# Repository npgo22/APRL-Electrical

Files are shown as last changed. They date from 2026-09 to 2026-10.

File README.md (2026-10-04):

# APRL KiCad Projects

APRL KiCad Projects.

## Setup
First, clone the repository with `git clone`. GitHub has a button which gives you the command to do this.
Then, you will have to use `git lfs pull` to get all the 3D models and images.

The projects here rely on `APRL_LIBS` and `KICAD_USER_TEMPLATE_DIR` being set. You can do this by:

1. Going to Preferences > Configure Paths...
2. Setting `APRL_LIBS` to wherever you cloned this repo + `/kicadlibs`.
3. Setting `KICAD_USER_TEMPLATE_DIR` to whatever you set in (2) + `/templates`

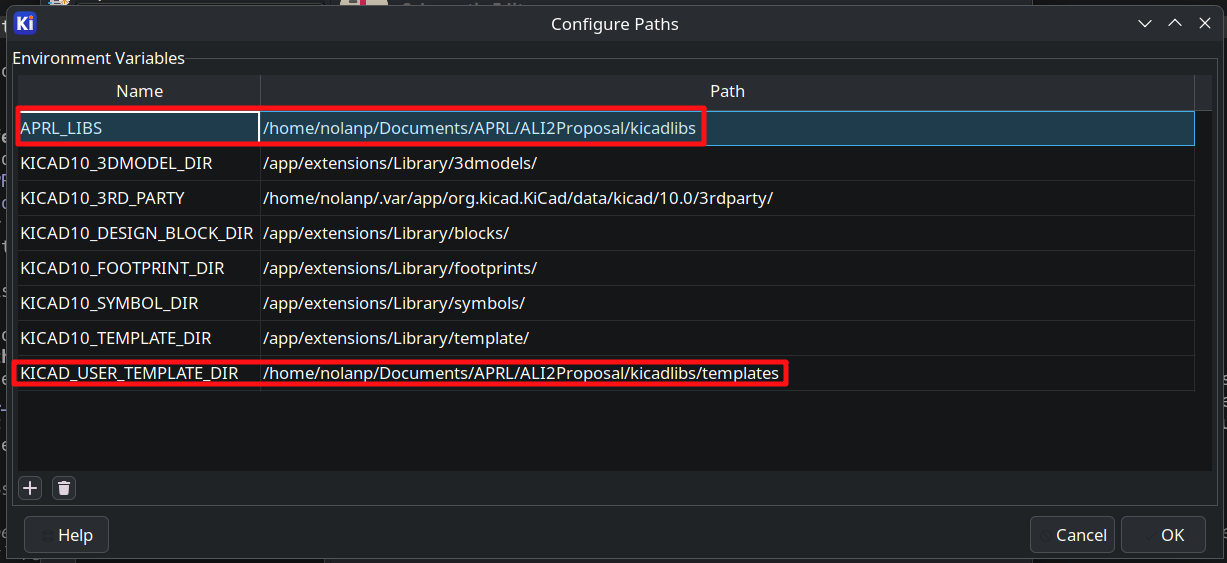
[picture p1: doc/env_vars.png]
Screenshot of the environment variables being set


## New ALI (Current Project for FQ2026)

### Design
The exigence of this endeavour is twofold:
1. To test the analog frontend designs of our proposed boards for DPF
2. To replace the confusing and elaborate ALI electronics with something that is far better documented and easier to use

The ALI itself can continue to be used for years to come and this reworking of the electronics will not impact it at all. This is going to be its own separate electrical box altogether. The ALI has the following additional limitations, too:
1. Limited I/O
2. Bonded grounds between +24/12/5V power supplies
3. Unknown board-level design decisions/trade-offs made in off-the-shelf components leading to strange artifacts in various measurements
4. Is generally really difficult to understand
5. Mixes bodge-wired custom electronics, off-the-shelf parts, and protoboards
6. Generally has fairly poor mounting
7. Makes use of fairly terrible connectors which are partially damaged and/or have shields which are not properly tied to case GND
8. Is completely full, thus making it impossible to add more electronics
9. Has no methods of cooling, sans the empty hold in the side of the box which completely negate the weather rating of the box itself
10. Uses heterogenous embedded computing ecosystems, requiring cross-domain knowledge of embassy, STM32Cube, and Arduino while doing every single one of them somewhat wrong in one way or another
11. Lacks feedback in many places (error logging namely)
12. Is generally just really hard to work with

Therefore, we have started work on a true replacement. Each of the modules serve a specific task, and are hooked to a common ethernet-based network which is far more performant than the original layout while simultaneously being easier to understand and expand. If you want more I/O, you can just simply add another board within a few minutes. Likewise, by opting for cutouts in the enclosure over dedicated port holes, it is also far easier to revise significant parts of the design without needing to drill through steel. 

#### Power
This system is +5V and +24V only, with +3.3V regulated on each board.

### CANBUS vs Ethernet
On the ground station, we are planning to use Ethernet instead of CANBUS. While this means our session protocol will not be tested in a real-world hotfire scenario, it does mean we can fully exploit each of the features offered by ethernet:
- Higher bandwidth (upwards of ~50x) means we don't have to throttle anything including error logging
- Natural isolation means we don't need any special tricks to get grounded thermocouples to work
- Is just generally far more pleasant to work with
- Does not limit future design decisions should we decide to reuse anything

Each of the modules will have a CAN transceiver anyway available for testing.

## Repository layout

```
kicadlibs/                                 Shared KiCad libraries, referenced as ${APRL_LIBS}
  aprl/                                      APRL's custom symbols and footprints
  aprl/*-noct.pretty                         "aprl/" but without courtyards
  vendor/                                    Third-party libs
  kicad/                                     Vendored stock KiCad libraries
  models/                                    3D models
  APRL_*_Sheet.kicad_wks                     Drawing sheets
  jlcpcb-4layer.kicad_dru                    Canonical JLCPCB design rules
.github/scripts                              Helper scripts runnable via Just and GH actions

ali/v2/                                    New ALI electronics
ali/v1/                                    Old ALI electronics
ophio/                                     DPF Vehicle Boards
misc/                                      Other endeavours
```

## What's not in this repo
- Old code (incl thermocouple 1A's CubeMX and Embassy variants)
- Prototypes (pending ordering)
- ALI ADC hardware (pending import)

## AI Usage
You may use AI to research topics and to write one-off scripts which do minor modifications and automate tedious, minor tasks. For example, if you need to color in a bunch of models feel free to.

What you *cannot* use it for is end to end electrical design, layout, and documentation. Documents should be written by people, and a schematic falls under this category. Likewise, using AI to automate layout is A. ineffective because it does not generate high-quality layouts and B. defeats the purpose of this club, which is to learn about electronics.

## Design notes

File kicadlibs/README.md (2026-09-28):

# KiCad Libraries

Libraries for KiCad. Reference them with `${APRL_LIBS}/...`, set to this folder
in Preferences -> Configure Paths.

## aprl/

First-party libs drawn by APRL. Every library is named `APRL_*`.

## kicad/

The stock KiCad libraries, vendored whole because KiCad devs hate electrical
engineers. Refresh with `just vendor-kicad-flatpak`.

## vendor/

Third-party libs generated by others.

## models/

3D models for every library, flat and keyed by filename. Referenced as
`${APRL_LIBS}/models/<file>`.

## Drawing sheets and rules

`APRL_Schematic_Sheet.kicad_wks`, `APRL_Layout_Sheet.kicad_wks` and
`jlcpcb-4layer.kicad_dru`. Title-block fields are project text variables.

## Adding a part

Symbol goes in the `APRL_*.kicad_sym` matching its function, footprint in the
matching `APRL_*.pretty`, 3D model in `models/`. Third-party parts go in
`vendor/`.

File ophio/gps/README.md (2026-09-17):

# Flight Computer / GPS (v1)

Flight computer board with GPS integration.

## KiBot

```sh
kibot -c gps.kibot.yaml
```

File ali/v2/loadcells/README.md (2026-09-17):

# Load Cell DAQ (LC)

A board that reads a load cell reading. Typically used for engine thrust measurements.

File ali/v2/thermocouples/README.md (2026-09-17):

# Thermocouple DAQ (TC)

A board that reads temperatures.

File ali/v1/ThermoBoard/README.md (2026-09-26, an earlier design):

# APRL Thermocouple Board
This is the "old" thermocouple board which was made
as an upgrade to old ALI.

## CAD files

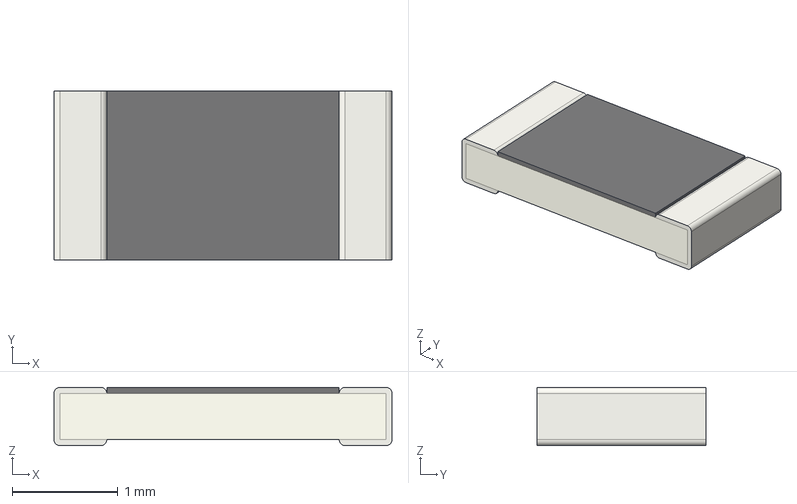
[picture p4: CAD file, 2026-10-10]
kicadlibs/models/Fuse_1206_3216Metric.step
3.20 x 1.60 x 0.55 mm

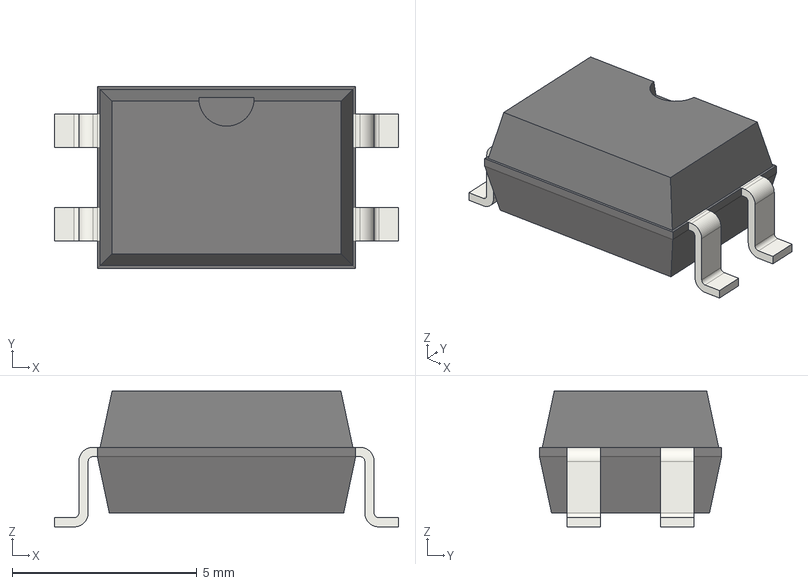
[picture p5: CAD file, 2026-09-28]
kicadlibs/models/SMDIP-4_W9.53mm.step
9.32 x 4.93 x 3.68 mm

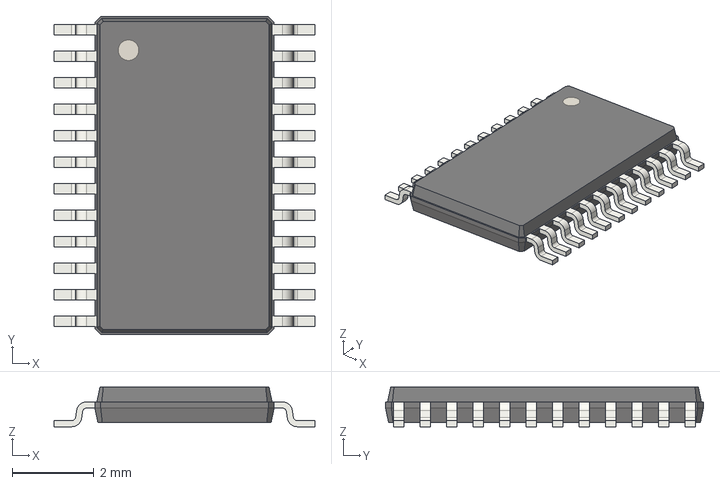
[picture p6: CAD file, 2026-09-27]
kicadlibs/models/TSSOP-24_4.4x7.8mm_P0.65mm.step
6.40 x 7.80 x 0.97 mm

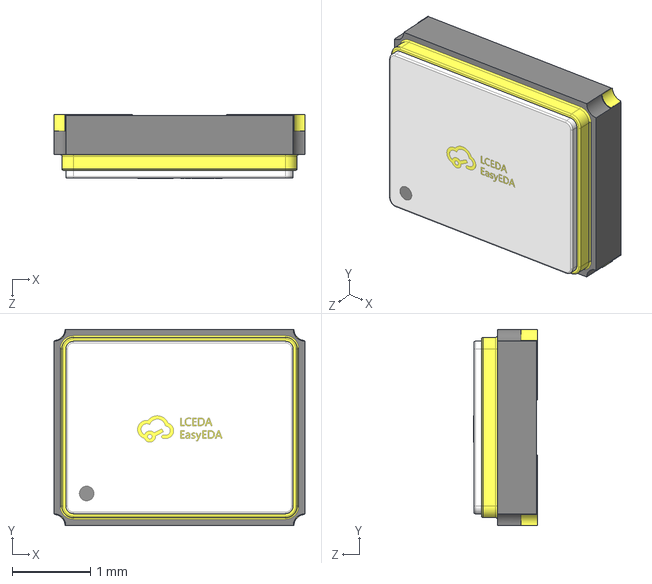
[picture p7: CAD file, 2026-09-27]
kicadlibs/models/Oscillator_SCTF_SX3M_3.2x2.5mm.step
3.20 x 2.50 x 0.811 mm

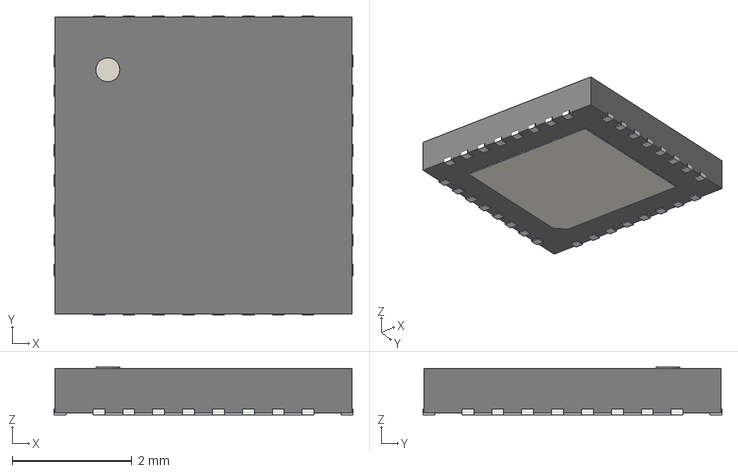
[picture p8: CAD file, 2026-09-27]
kicadlibs/models/Texas_RHB0032E_VQFN-32-1EP_5x5mm_P0.5mm_EP3.45x3.45mm.step
5.00 x 5.00 x 0.8 mm

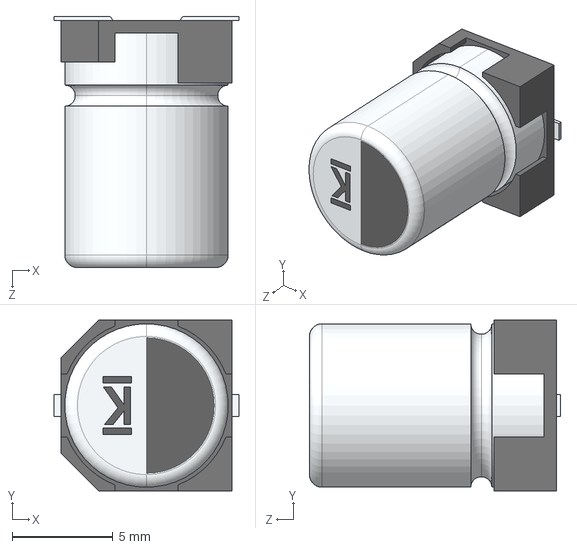
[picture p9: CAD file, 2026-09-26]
kicadlibs/models/CP_Elec_8x12.2_KEMET_A767_KS.step
9.20 x 8.50 x 12.5 mm

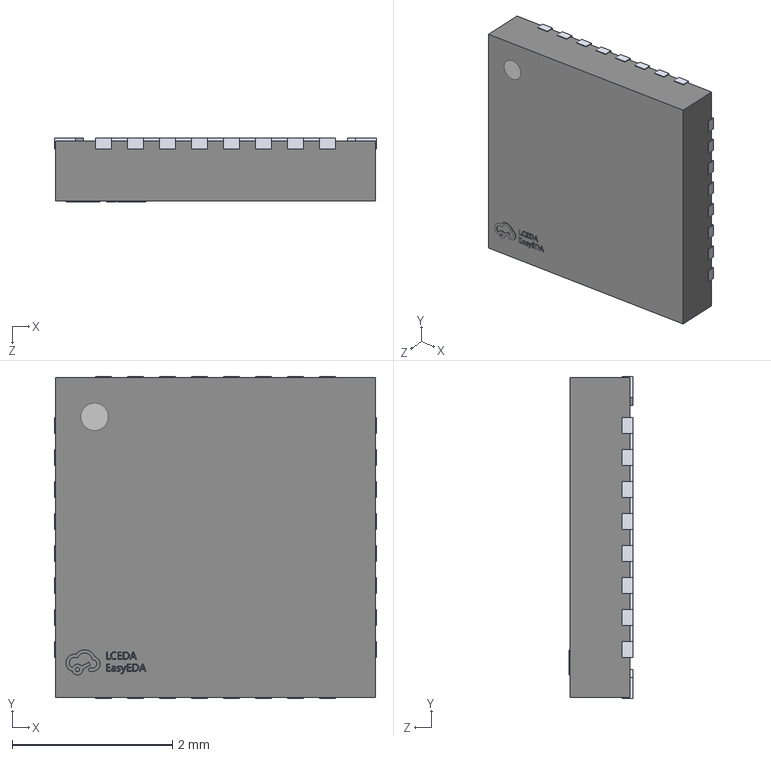
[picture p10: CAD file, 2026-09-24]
kicadlibs/models/WQFN-32_L4.0-W4.0-P0.40-TL-EP2.7.step
4.02 x 4.02 x 0.795 mm

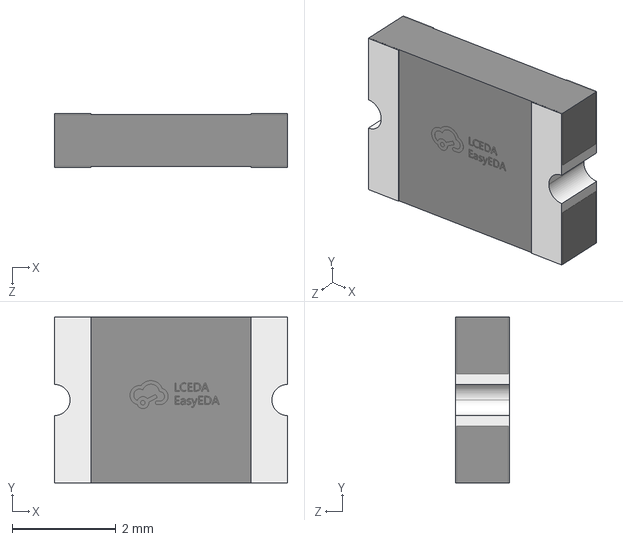
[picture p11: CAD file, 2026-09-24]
kicadlibs/models/Fuse_1812L_Littelfuse.step
4.50 x 3.20 x 1.04 mm

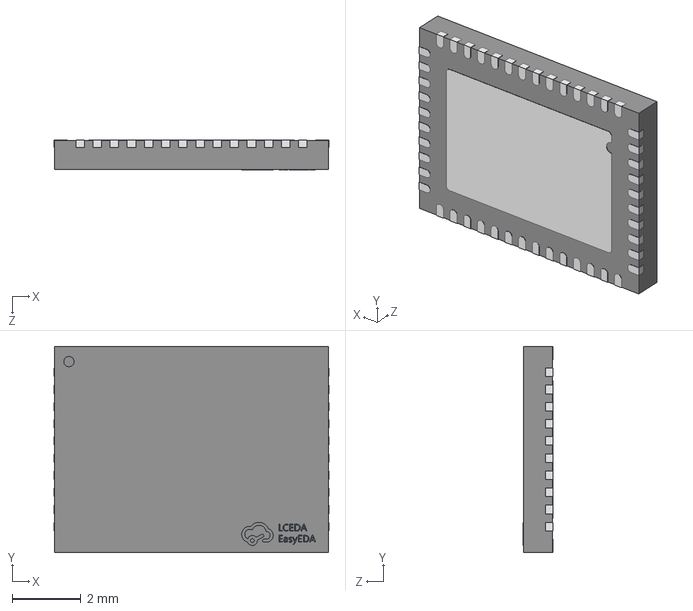
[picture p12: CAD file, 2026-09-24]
kicadlibs/models/QFN-48_L8.0-W6.0-P0.50-TL-EP.step
8.02 x 6.02 x 0.87 mm

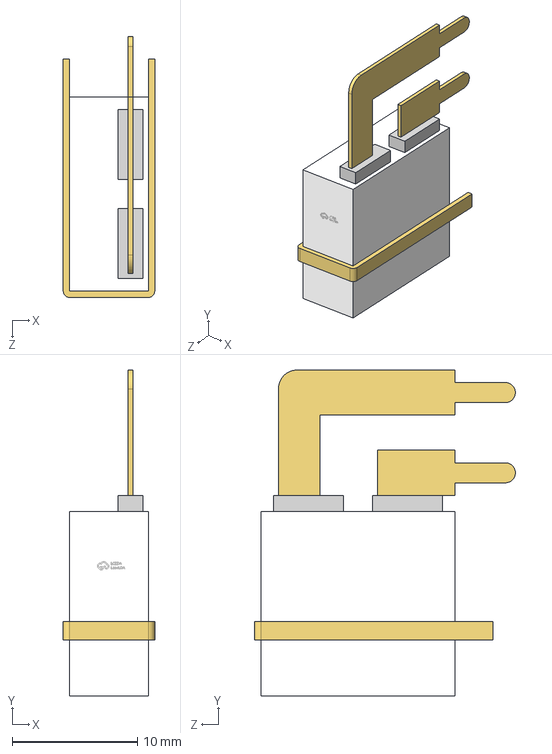
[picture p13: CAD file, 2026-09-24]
kicadlibs/models/PCC-SMP-V-K.step
7.30 x 26.0 x 20.8 mm

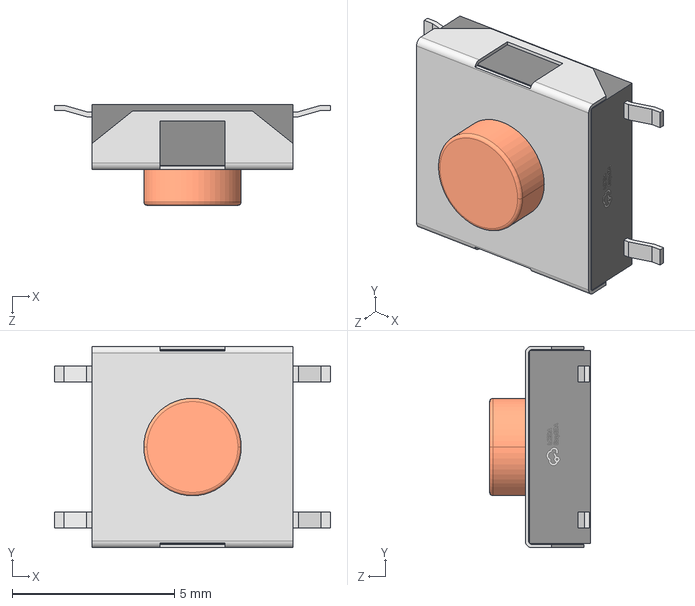
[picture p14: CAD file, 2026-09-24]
kicadlibs/models/SW-SMD_4P-L6.2-W6.2-P4.50-LS8.6.step
8.50 x 6.20 x 3.10 mm

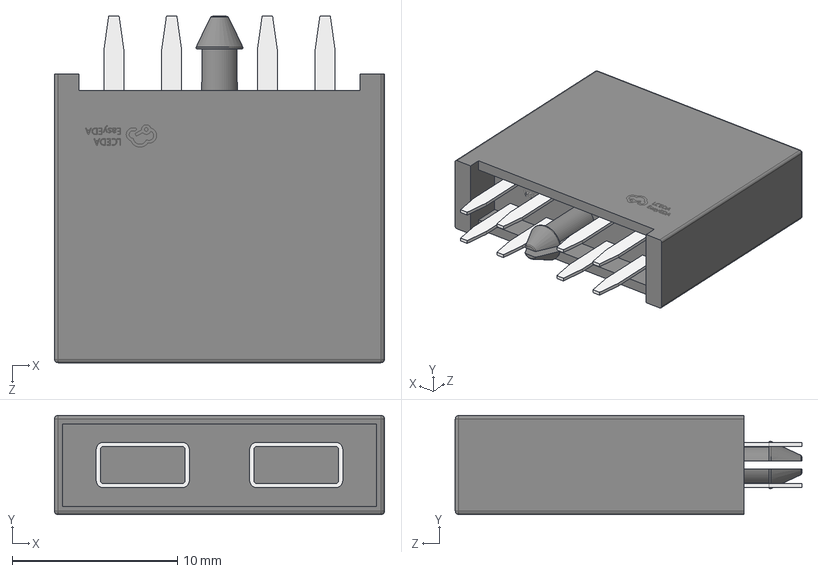
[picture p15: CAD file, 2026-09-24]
kicadlibs/models/178.6165.0001.step
20.0 x 6.00 x 21.0 mm

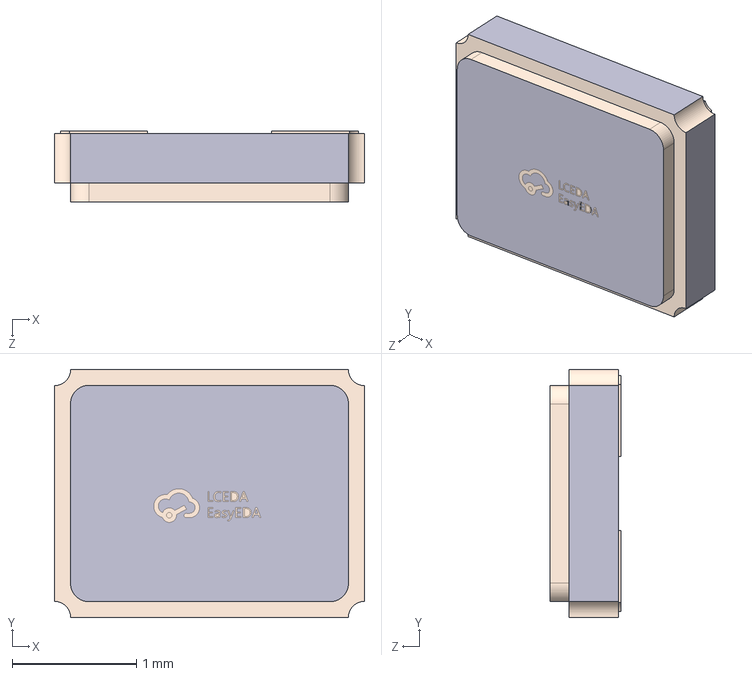
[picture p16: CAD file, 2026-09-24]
kicadlibs/models/OSC-SMD_4P-L2.5-W2.0-BL.step
2.50 x 2.00 x 0.571 mm

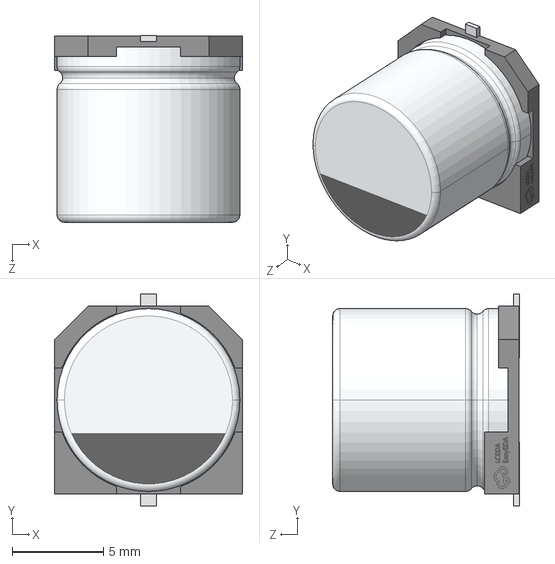
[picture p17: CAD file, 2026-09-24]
kicadlibs/models/CAP-SMD_BD10.0-L10.3-W10.3-LS11.0-FD.step
10.3 x 11.6 x 10.2 mm

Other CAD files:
kicadlibs/models/Texas_HTSSOP-14-1EP_4.4x5mm_P0.65mm_EP3.4x5mm_Mask3.155x3.255mm.step
kicadlibs/models/WSON-6-1EP_2x2mm_P0.65mm_EP1x1.6mm.step
kicadlibs/models/Molex_CLIK-Mate_503175-0500_1x05-1MP_P1.50mm_Horizontal.step
kicadlibs/models/GPSM-SMD_NEO-M8N.step
kicadlibs/models/132203-12.stp
kicadlibs/models/2132250231.stp
kicadlibs/models/BatteryHolder_Keystone_1042_1x18650.step
kicadlibs/models/CRYSTAL-SMD_4P-L3.2-W2.5-BL-2.step
kicadlibs/models/C_0402_1005Metric.step
kicadlibs/models/C_0603_1608Metric.step
kicadlibs/models/C_0805_2012Metric.step
kicadlibs/models/Crystal_SMD_3225-4Pin_3.2x2.5mm.step
kicadlibs/models/DFN-8-1EP_3x3mm_P0.65mm_EP1.55x2.4mm.step
kicadlibs/models/DFN8_2x3MC_MCH.step
kicadlibs/models/DIP-4_W7.62mm_SMDSocket.step
kicadlibs/models/D_SMF.step
kicadlibs/models/D_SOD-123F.step
kicadlibs/models/D_SOD-323.step
kicadlibs/models/Fuse_0805_2012Metric.step
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

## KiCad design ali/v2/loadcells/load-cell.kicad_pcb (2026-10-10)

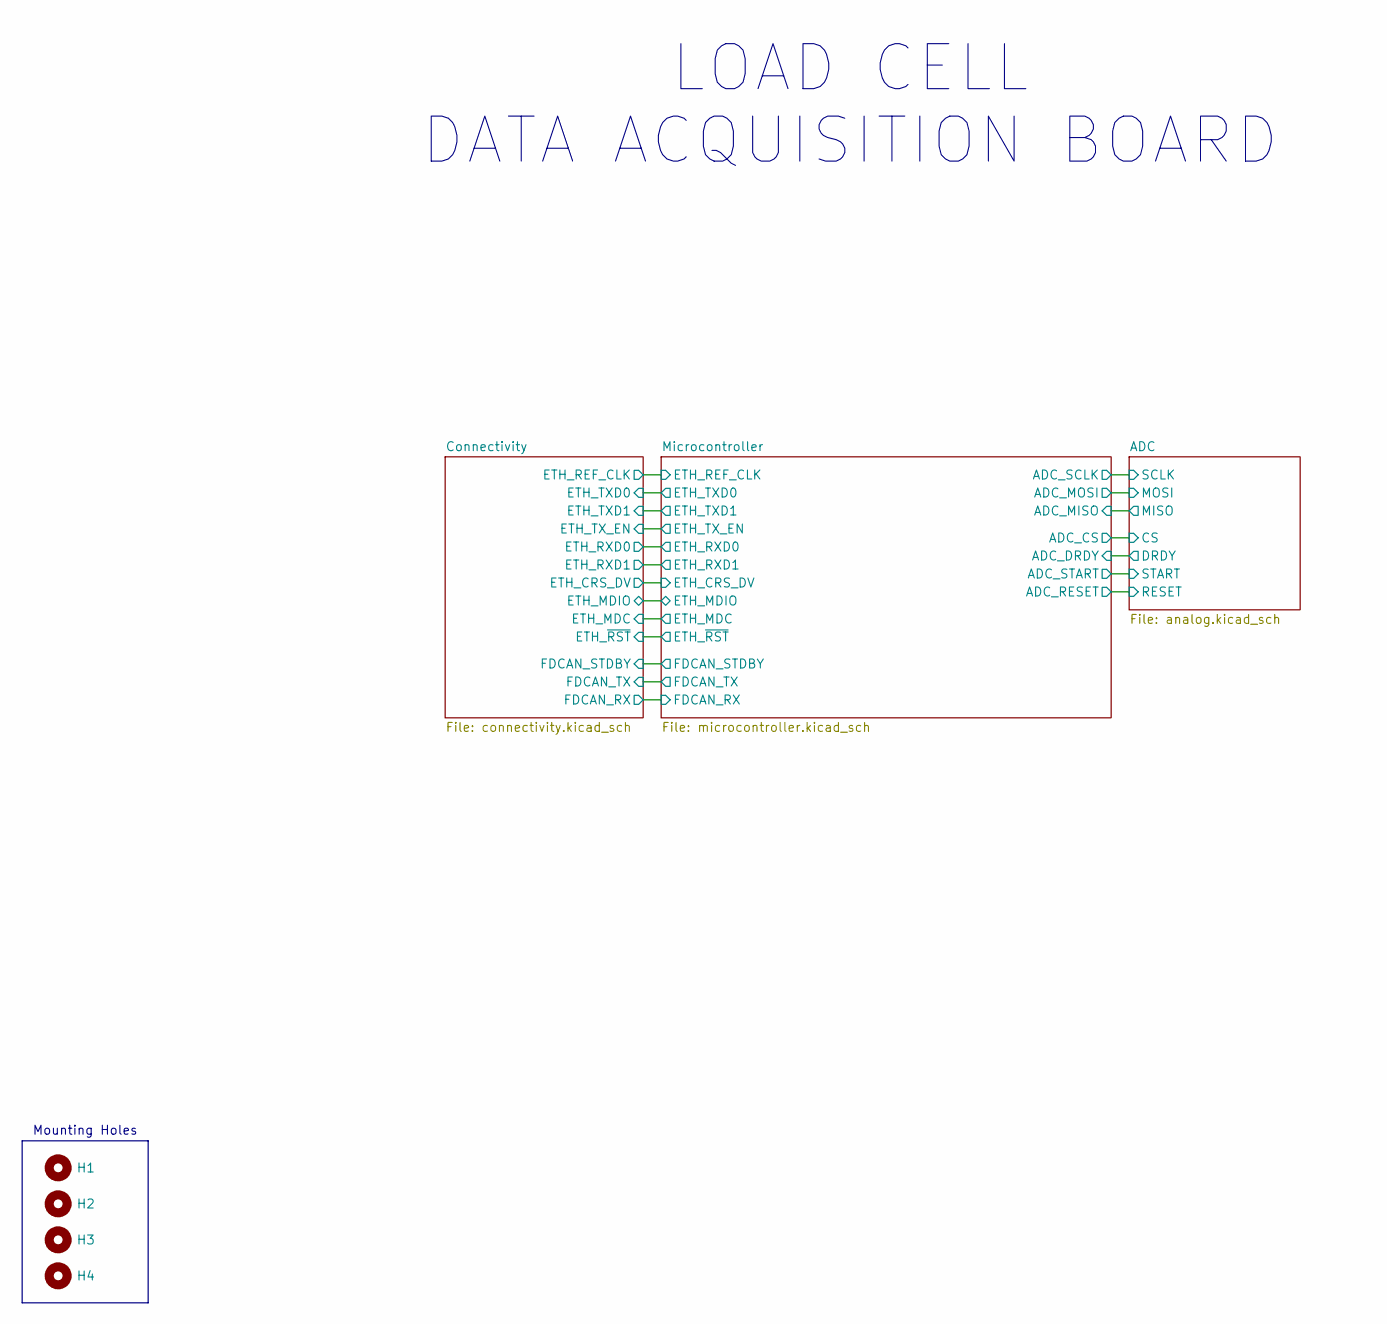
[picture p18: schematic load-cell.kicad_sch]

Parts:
H1, H2, H3, H4: MountingHole; MountingHole_3.2mm_M3

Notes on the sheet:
LOAD CELL DATA ACQUISITION BOARD
Mounting Holes

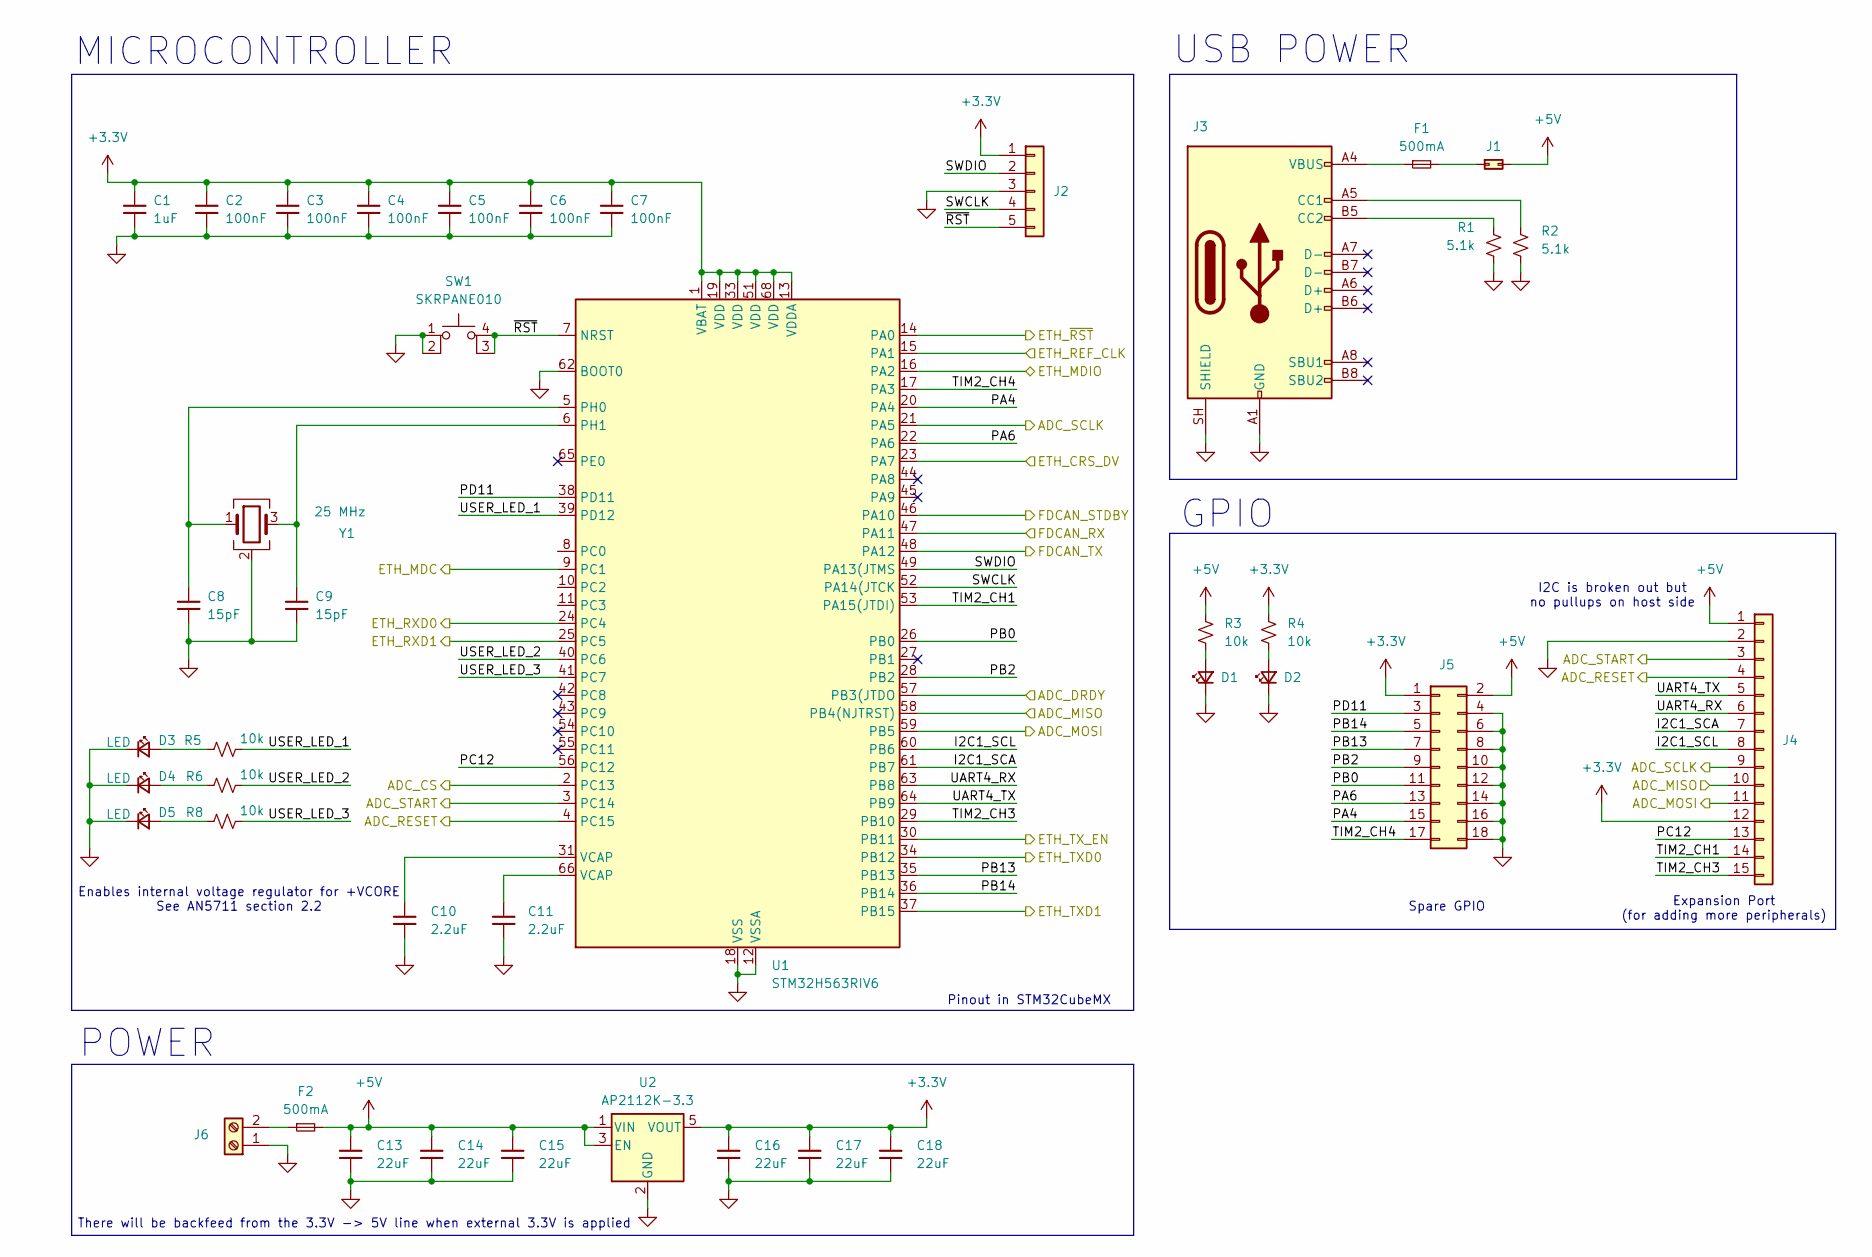
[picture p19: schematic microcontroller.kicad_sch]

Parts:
C1: 1uF; C_0603; MPN GRM188D72A105KE01
C2, C3, C4, C5, C6, C7: 100nF; C_0603; MPN GRM188R72A104KA35
C8, C9: 15pF; C_0603; MPN GRM1885C2E150FW07
C10, C11: 2.2uF; C_0603; MPN GRM188R71A225KE15
C13, C14, C15, C16, C17, C18: 22uF; C_0805; MPN GRM21BZ71A226ME15
D1, D2, D3, D4, D5: LED; LED_0603
F1, F2: 500mA; Fuse_0805_2012Metric; MPN 0805L050WR
J1: Conn_02x01; PinHeader_1x02_P2.54mm_Vertical
J2: Conn_01x05; Molex_CLIK-Mate_503159-0501_1x05-1MP_P1.50mm_Vertical; MPN 503159-0501
J3: USB_C_Receptacle_USB2.0_16P; USB_C_Receptacle_G-Switch_GT-USB-7051x; MPN GT-USB-7051A
J4: Conn_01x15; Molex_CLIK-Mate_503159-1501_1x15-1MP_P1.50mm_Vertical; MPN 503159-1501
J5: Conn_02x09_Counter_Clockwise; IDC-Header_2x09_P2.54mm_Vertical
J6: Screw_Terminal_01x02; PhoenixContact_MSTBV_2,5_2-GF-5,08_1x02_P5.08mm_Vertical_Th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; MPN MSTBV 2,5/ 2-GF-5,08
R1, R2: 5.1k; R_0603; MPN RC0603FR-075K1L
R3, R4, R5, R6, R8: 10k; R_0603; MPN RC0603FR-0710KL
SW1: SKRPANE010; MPN SKRPANE010
U1: STM32H563RIV6; QFN-68-1EP_8x8mm_P0.4mm_EP6.4x6.4mm; MPN STM32H563RIV6
U2: AP2112K-3.3; SOT-23-5; MPN AP2112K-3.3TRG1
Y1: 25 MHz; 3225-4P-L; MPN X1E0000210139

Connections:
+3.3V: C1.1, C2.1, C3.1, C4.1, C5.1, C6.1, C7.1, C16.1, C17.1, C18.1, J2.1, J4.12, J5.1, R4.1, U1.1 (VBAT), U1.13 (VDDA), U1.19 (VDD), U1.33 (VDD), U1.51 (VDD), U1.68 (VDD), U2.5 (VOUT); also elsewhere on the board
+5V: C13.1, C14.1, C15.1, F2.2, J1.2, J4.1, J5.2, R3.1, U2.1 (VIN), U2.3 (EN); also elsewhere on the board
/ADC/CS: U1.2 (PC13); also elsewhere on the board
/ADC/DRDY: U1.57 (PB3(JTDO); also elsewhere on the board
/ADC/MISO: J4.10, U1.58 (PB4(NJTRST)); also elsewhere on the board
/ADC/MOSI: J4.11, U1.59 (PB5); also elsewhere on the board
/ADC/RESET: J4.4, U1.4 (PC15); also elsewhere on the board
/ADC/SCLK: J4.9, U1.21 (PA5); also elsewhere on the board
/ADC/START: J4.3, U1.3 (PC14); also elsewhere on the board
/Connectivity/ETH_CRS_DV: U1.23 (PA7); also elsewhere on the board
/Connectivity/ETH_MDC: U1.9 (PC1); also elsewhere on the board
/Connectivity/ETH_MDIO: U1.16 (PA2); also elsewhere on the board
/Connectivity/ETH_REF_CLK: U1.15 (PA1); also elsewhere on the board
/Connectivity/ETH_RXD0: U1.24 (PC4); also elsewhere on the board
/Connectivity/ETH_RXD1: U1.25 (PC5); also elsewhere on the board
/Connectivity/ETH_TXD0: U1.34 (PB12); also elsewhere on the board
/Connectivity/ETH_TXD1: U1.37 (PB15); also elsewhere on the board
/Connectivity/ETH_TX_EN: U1.30 (PB11); also elsewhere on the board
/Connectivity/ETH_~RST: U1.14 (PA0); also elsewhere on the board
/Connectivity/FDCAN_RX: U1.47 (PA11); also elsewhere on the board
/Connectivity/FDCAN_STDBY: U1.46 (PA10); also elsewhere on the board
/Connectivity/FDCAN_TX: U1.48 (PA12); also elsewhere on the board
/Microcontroller/I2C1_SCA: J4.7, U1.61 (PB7)
/Microcontroller/I2C1_SCL: J4.8, U1.60 (PB6)
/Microcontroller/PA4: J5.15, U1.20 (PA4)
/Microcontroller/PA6: J5.13, U1.22 (PA6)
/Microcontroller/PB0: J5.11, U1.26 (PB0)
/Microcontroller/PB2: J5.9, U1.28 (PB2)
/Microcontroller/PB13: J5.7, U1.35 (PB13)
/Microcontroller/PB14: J5.5, U1.36 (PB14)
/Microcontroller/PC12: J4.13, U1.56 (PC12)
/Microcontroller/PD11: J5.3, U1.38 (PD11)
/Microcontroller/SWCLK: J2.4, U1.52 (PA14(JTCK)
/Microcontroller/SWDIO: J2.2, U1.49 (PA13(JTMS)
/Microcontroller/TIM2_CH1: J4.14, U1.53 (PA15(JTDI))
/Microcontroller/TIM2_CH3: J4.15, U1.29 (PB10)
/Microcontroller/TIM2_CH4: J5.17, U1.17 (PA3)
/Microcontroller/UART4_RX: J4.6, U1.63 (PB8)
/Microcontroller/UART4_TX: J4.5, U1.64 (PB9)
/Microcontroller/USER_LED_1: R5.2, U1.39 (PD12)
/Microcontroller/USER_LED_2: R6.2, U1.40 (PC6)
/Microcontroller/USER_LED_3: R8.2, U1.41 (PC7)
/Microcontroller/~RST: J2.5, SW1.3 (K), SW1.4 (A), U1.7 (NRST)
GND: C1.2, C2.2, C3.2, C4.2, C5.2, C6.2, C7.2, C8.2, C9.2, C10.2, C11.2, C13.2, C14.2, C15.2, C16.2, C17.2, C18.2, D1.1 (K), D2.1 (K), D3.1 (K), D4.1 (K), D5.1 (K), J2.3, J3.A1 (GND), J3.A12 (GND), J3.B1 (GND), J3.B12 (GND), J3.SH (SHIELD), J4.2, J5.4, J5.6, J5.8, J5.10, J5.12, J5.14, J5.16, J5.18, J6.1, R1.1, R2.2, SW1.1, SW1.2, U1.12 (VSSA), U1.18 (VSS), U1.32 (VSS), U1.50 (VSS), U1.62 (BOOT0), U1.67 (VSS), U1.69 (VSS), U2.2 (GND), Y1.2 (G), Y1.4 (G); also elsewhere on the board
unnamed: C10.1, U1.31 (VCAP)
unnamed: C11.1, U1.66 (VCAP)
unnamed: D1.2 (A), R3.2
unnamed: D2.2 (A), R4.2
unnamed: D3.2 (A), R5.1
unnamed: D4.2 (A), R6.1
unnamed: D5.2 (A), R8.1
unnamed: F1.1, J3.A4 (VBUS), J3.A9 (VBUS), J3.B4 (VBUS), J3.B9 (VBUS)
unnamed: F1.2, J1.1
unnamed: J3.A5 (CC1), R2.1
unnamed: J3.B5 (CC2), R1.2
unnamed: F2.1, J6.2
unnamed: C8.1, U1.5 (PH0), Y1.1
unnamed: C9.1, U1.6 (PH1), Y1.3

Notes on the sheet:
Enables internal voltage regulator for +VCORE See AN5711 section 2.2
MICROCONTROLLER
There will be backfeed from the 3.3V -> 5V line when external 3.3V is applied
USB POWER
Spare GPIO
POWER
Expansion Port (for adding more peripherals)
Pinout in STM32CubeMX
I2C is broken out but no pullups on host side
GPIO

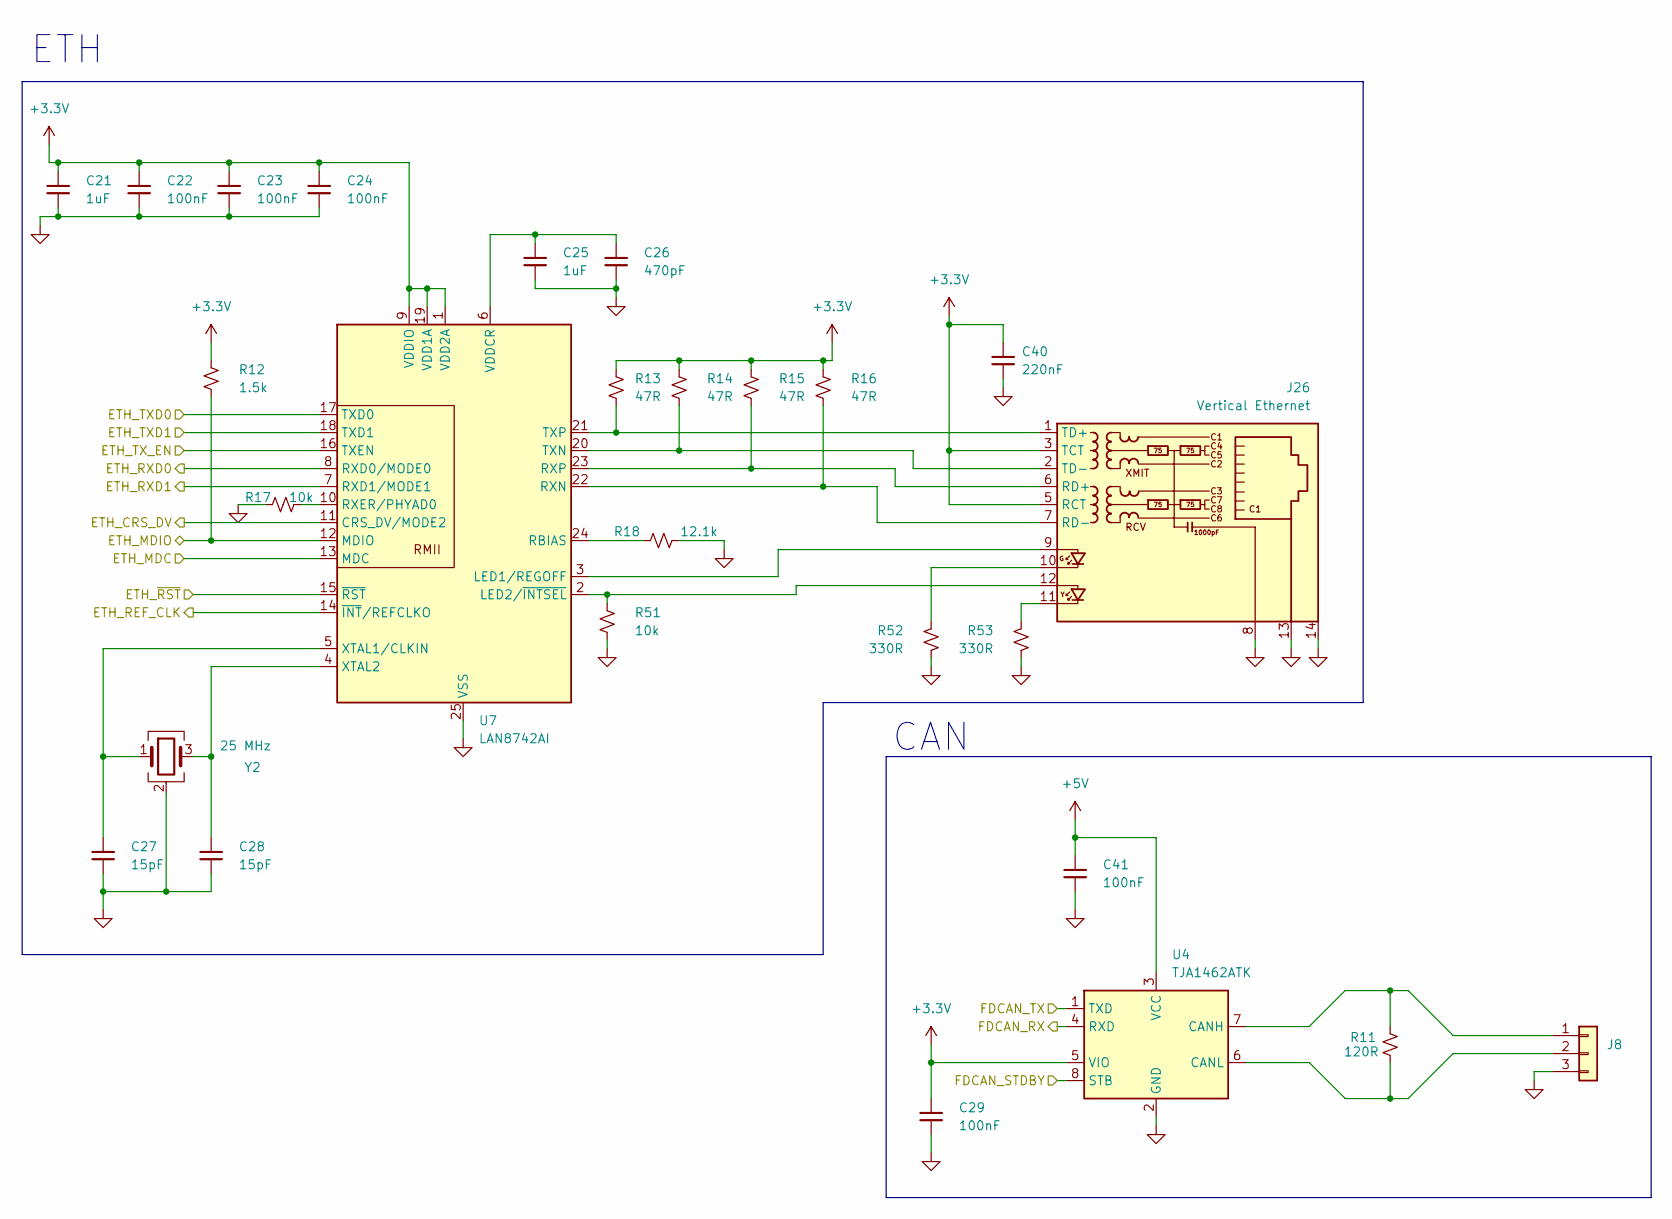
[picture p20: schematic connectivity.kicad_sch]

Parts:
C21, C25: 1uF; C_0603; MPN GRM188D72A105KE01
C22, C23, C24, C29, C41: 100nF; C_0603; MPN GRM188R72A104KA35
C26: 470pF; C_0603; MPN GRM1885C1H471JA01
C27, C28: 15pF; C_0603; MPN GRM1885C2E150FW07
C40: 220nF; C_0603; MPN GRM188R71H224KAC4
J8: Conn_01x03; Molex_CLIK-Mate_503159-0301_1x03-1MP_P1.50mm_Vertical; MPN 503159-0301
J26: Vertical Ethernet; RJ45_Hanrun_HY951180A_Vertical; MPN HY951180A
R11: 120R; R_0603; MPN AC0603FR-07120RL
R12: 1.5k; R_0603; MPN RC0603FR-071K5L
R13, R14, R15, R16: 47R; R_0603; MPN RC0603FR-0747RL
R17, R51: 10k; R_0603; MPN RC0603FR-0710KL
R18: 12.1k; R_0603; MPN RT0603BRD0712K1L
R52, R53: 330R; R_0603; MPN RC0603FR-07330RL
U4: TJA1462ATK; HVSON-8-1EP_3x3mm_P0.65mm_EP1.6x2.4mm_ThermalVias; MPN TJA1462ATK/0Z
U7: LAN8742AI; VQFN-24-1EP_4x4mm_P0.5mm_EP2.5x2.5mm_ThermalVias; MPN LAN8742AI-CZ-TR
Y2: 25 MHz; 3225-4P-L; MPN X1E0000210139

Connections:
+3.3V: C21.1, C22.1, C23.1, C24.1, C29.1, C40.1, J26.3 (TCT), J26.5 (RCT), R12.1, R13.1, R14.1, R15.1, R16.1, U4.5 (VIO), U7.1 (VDD2A), U7.9 (VDDIO), U7.19 (VDD1A); also elsewhere on the board
+5V: C41.1, U4.3 (VCC); also elsewhere on the board
/Connectivity/ETH_CRS_DV: U7.11 (CRS_DV/MODE2); also elsewhere on the board
/Connectivity/ETH_MDC: U7.13 (MDC); also elsewhere on the board
/Connectivity/ETH_MDIO: R12.2, U7.12 (MDIO); also elsewhere on the board
/Connectivity/ETH_REF_CLK: U7.14 (~INT/REFCLKO); also elsewhere on the board
/Connectivity/ETH_RXD0: U7.8 (RXD0/MODE0); also elsewhere on the board
/Connectivity/ETH_RXD1: U7.7 (RXD1/MODE1); also elsewhere on the board
/Connectivity/ETH_TXD0: U7.17 (TXD0); also elsewhere on the board
/Connectivity/ETH_TXD1: U7.18 (TXD1); also elsewhere on the board
/Connectivity/ETH_TX_EN: U7.16 (TXEN); also elsewhere on the board
/Connectivity/ETH_~RST: U7.15 (~RST); also elsewhere on the board
/Connectivity/FDCAN_RX: U4.4 (RXD); also elsewhere on the board
/Connectivity/FDCAN_STDBY: U4.8 (STB); also elsewhere on the board
/Connectivity/FDCAN_TX: U4.1 (TXD); also elsewhere on the board
GND: C21.2, C22.2, C23.2, C24.2, C25.2, C26.2, C27.2, C28.2, C29.2, C40.2, C41.2, J8.3, J26.8, J26.13, J26.14, R17.1, R18.2, R51.2, R52.2, R53.2, U4.2 (GND), U4.9 (GND), U7.25 (VSS), Y2.2 (G), Y2.4 (G); also elsewhere on the board
unnamed: J8.1, R11.2, U4.7 (CANH)
unnamed: J8.2, R11.1, U4.6 (CANL)
unnamed: J26.10, R52.1
unnamed: J26.11, R53.1
unnamed: J26.6 (RD+), R15.2, U7.23 (RXP)
unnamed: J26.7 (RD-), R16.2, U7.22 (RXN)
unnamed: J26.1 (TD+), R13.2, U7.21 (TXP)
unnamed: J26.2 (TD-), R14.2, U7.20 (TXN)
unnamed: J26.9, U7.3 (LED1/REGOFF)
unnamed: J26.12, R51.1, U7.2 (LED2/~INTSEL)
unnamed: R18.1, U7.24 (RBIAS)
unnamed: R17.2, U7.10 (RXER/PHYAD0)
unnamed: C25.1, C26.1, U7.6 (VDDCR)
unnamed: C27.1, U7.5 (XTAL1/CLKIN), Y2.1
unnamed: C28.1, U7.4 (XTAL2), Y2.3

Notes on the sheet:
ETH
CAN

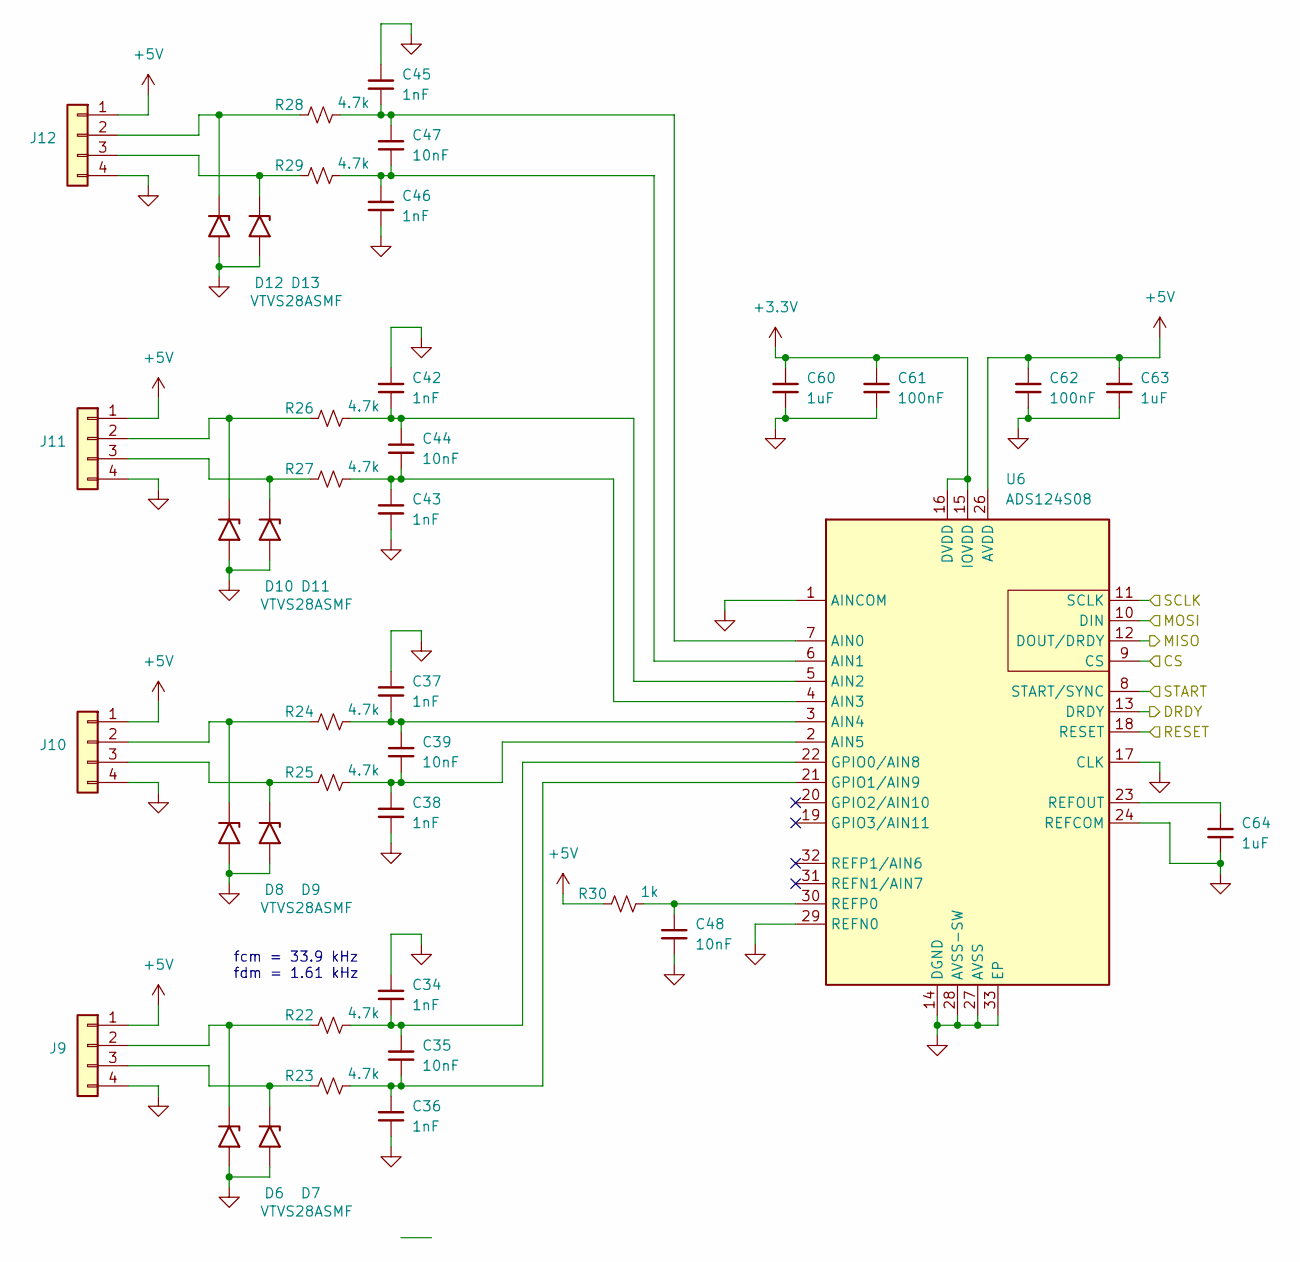
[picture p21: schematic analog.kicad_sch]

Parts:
C34, C36, C37, C38, C42, C43, C45, C46: 1nF; C_0603; MPN GRM1885C1H102FA01
C35, C39, C44, C47, C48: 10nF; C_0603; MPN GRM1885C1H103JA01
C60, C63, C64: 1uF; C_0603; MPN GRM188D72A105KE01
C61, C62: 100nF; C_0603; MPN GRM188R72A104KA35
D6, D7, D8, D9, D10, D11, D12, D13: VTVS28ASMF; D_SMF; MPN VTVS28ASMF-M3-08
J9, J10, J11, J12: Conn_01x04; Molex_CLIK-Mate_503159-0401_1x04-1MP_P1.50mm_Vertical; MPN 503159-0401
R22, R23, R24, R25, R26, R27, R28, R29: 4.7k; R_0603; MPN RT0603BRD074K7L
R30: 1k; R_0603; MPN RT0603BRD071KL
U6: ADS124S08; Texas_RHB0032M_VQFN-32-1EP_5x5mm_P0.5mm_EP2.1x2.1mm_Thermal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; MPN ADS124S08IRHBT

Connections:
+3.3V: C60.1, C61.1, U6.15 (IOVDD), U6.16 (DVDD); also elsewhere on the board
+5V: C62.1, C63.1, J9.1, J10.1, J11.1, J12.1, R30.1, U6.26 (AVDD); also elsewhere on the board
/ADC/CS: U6.9 (CS); also elsewhere on the board
/ADC/DRDY: U6.13 (DRDY); also elsewhere on the board
/ADC/MISO: U6.12 (DOUT/DRDY); also elsewhere on the board
/ADC/MOSI: U6.10 (DIN); also elsewhere on the board
/ADC/RESET: U6.18 (RESET); also elsewhere on the board
/ADC/SCLK: U6.11 (SCLK); also elsewhere on the board
/ADC/START: U6.8 (START/SYNC); also elsewhere on the board
GND: C34.2, C36.1, C37.2, C38.1, C42.2, C43.1, C45.2, C46.1, C48.1, C60.2, C61.2, C62.2, C63.2, C64.2, D6.2 (A2), D7.2 (A2), D8.2 (A2), D9.2 (A2), D10.2 (A2), D11.2 (A2), D12.2 (A2), D13.2 (A2), J9.4, J10.4, J11.4, J12.4, U6.1 (AINCOM), U6.14 (DGND), U6.17 (CLK), U6.24 (REFCOM), U6.27 (AVSS), U6.28 (AVSS-SW), U6.29 (REFN0), U6.33 (EP); also elsewhere on the board
unnamed: D6.1 (A1), J9.2, R22.1
unnamed: D7.1 (A1), J9.3, R23.1
unnamed: D8.1 (A1), J10.2, R24.1
unnamed: D9.1 (A1), J10.3, R25.1
unnamed: D10.1 (A1), J11.2, R26.1
unnamed: D11.1 (A1), J11.3, R27.1
unnamed: D12.1 (A1), J12.2, R28.1
unnamed: D13.1 (A1), J12.3, R29.1
unnamed: C45.1, C47.2, R28.2, U6.7 (AIN0)
unnamed: C46.2, C47.1, R29.2, U6.6 (AIN1)
unnamed: C42.1, C44.2, R26.2, U6.5 (AIN2)
unnamed: C43.2, C44.1, R27.2, U6.4 (AIN3)
unnamed: C37.1, C39.2, R24.2, U6.3 (AIN4)
unnamed: C38.2, C39.1, R25.2, U6.2 (AIN5)
unnamed: C34.1, C35.2, R22.2, U6.22 (GPIO0/AIN8)
unnamed: C35.1, C36.2, R23.2, U6.21 (GPIO1/AIN9)
unnamed: C64.1, U6.23 (REFOUT)
unnamed: C48.2, R30.2, U6.30 (REFP0)

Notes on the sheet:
fcm = 33.9 kHz fdm = 1.61 kHz

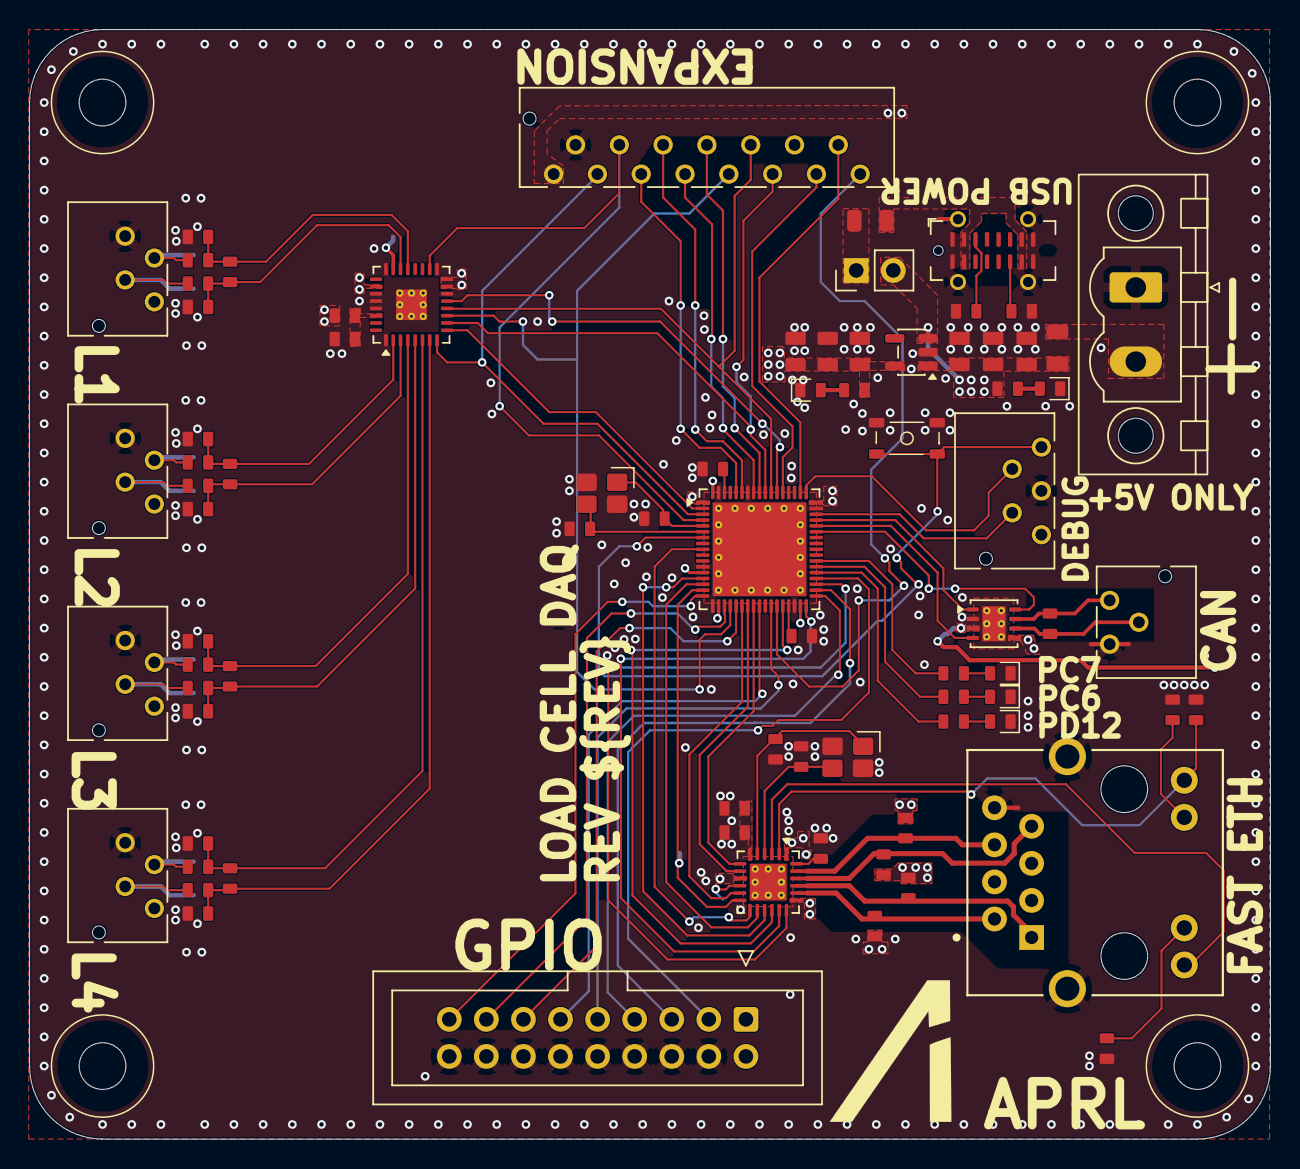
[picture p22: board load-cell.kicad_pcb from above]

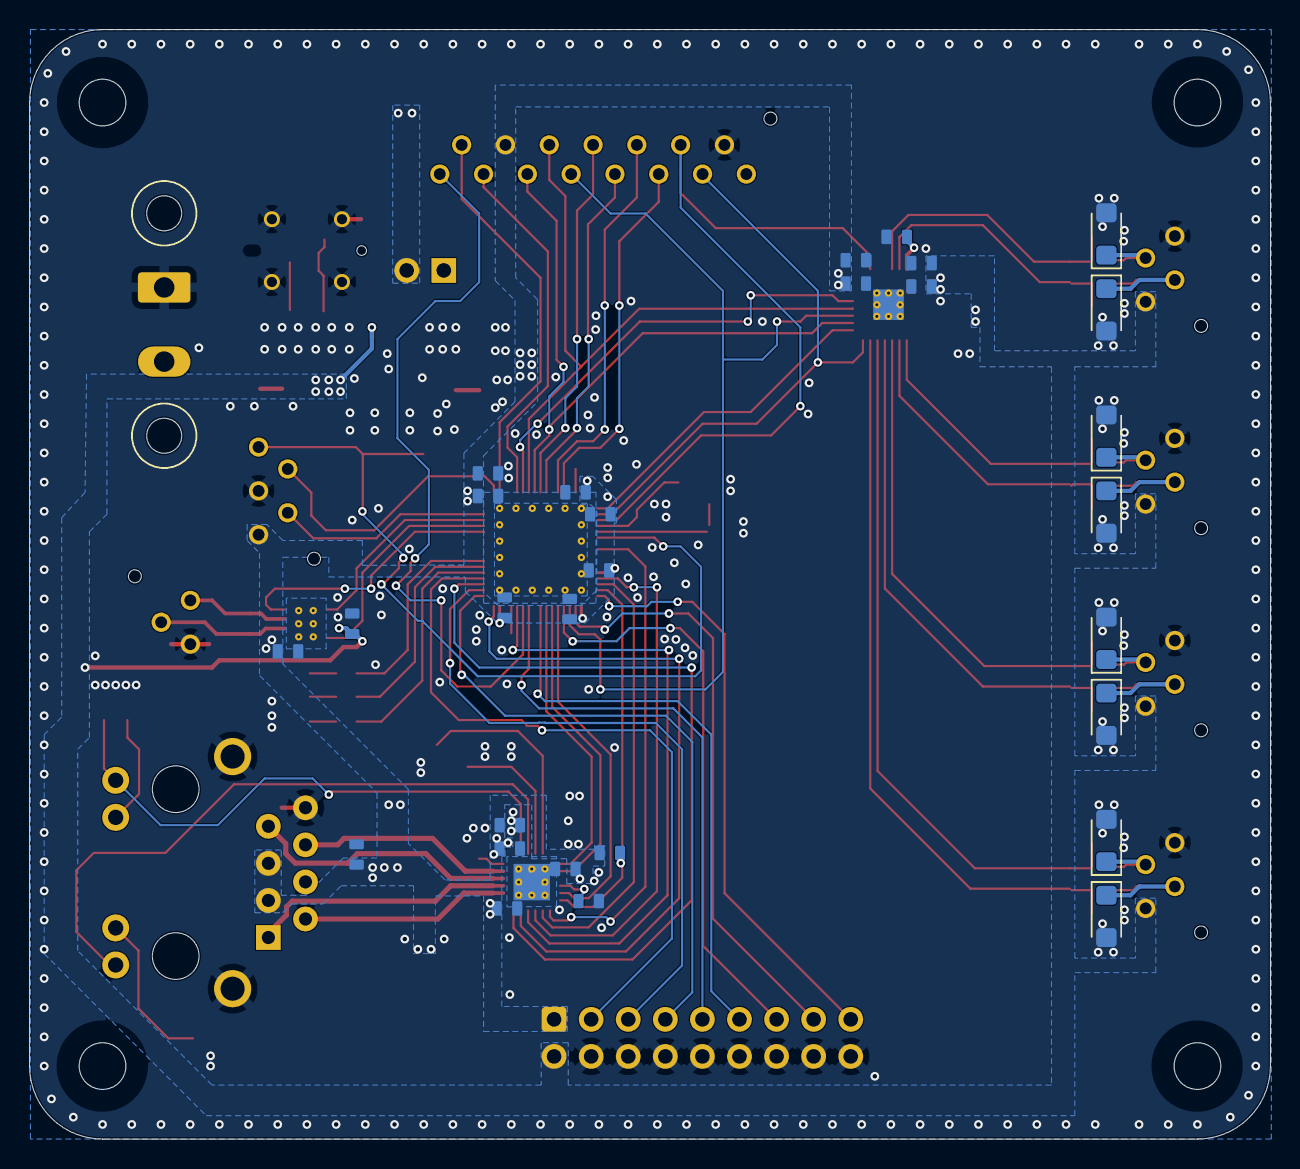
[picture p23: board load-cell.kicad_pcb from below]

Board: 4 copper layers, 85.0 x 76.0 mm, 112 parts (29 on the bottom side), 91 nets.

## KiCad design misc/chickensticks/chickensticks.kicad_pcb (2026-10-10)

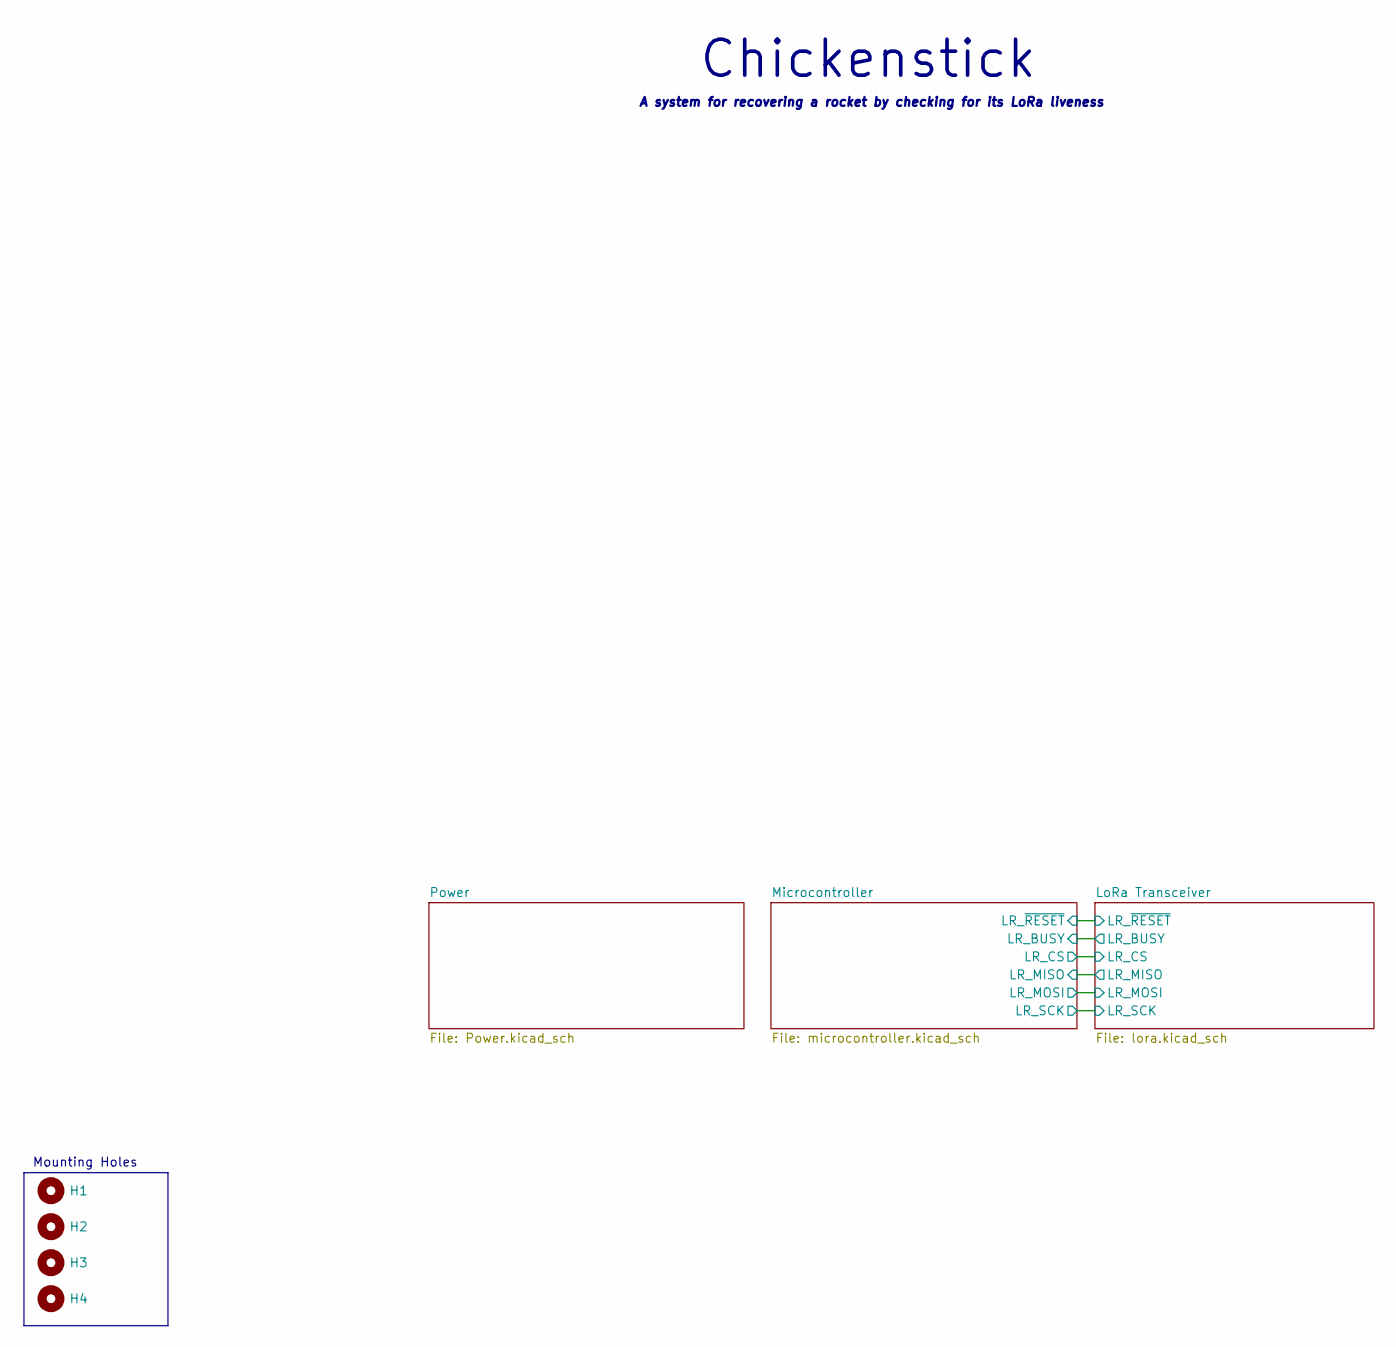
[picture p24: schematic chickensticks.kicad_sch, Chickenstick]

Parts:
H1, H2, H3, H4: MountingHole; MountingHole_3.2mm_M3

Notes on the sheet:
Chickenstick
A system for recovering a rocket by checking for its LoRa liveness
Mounting Holes

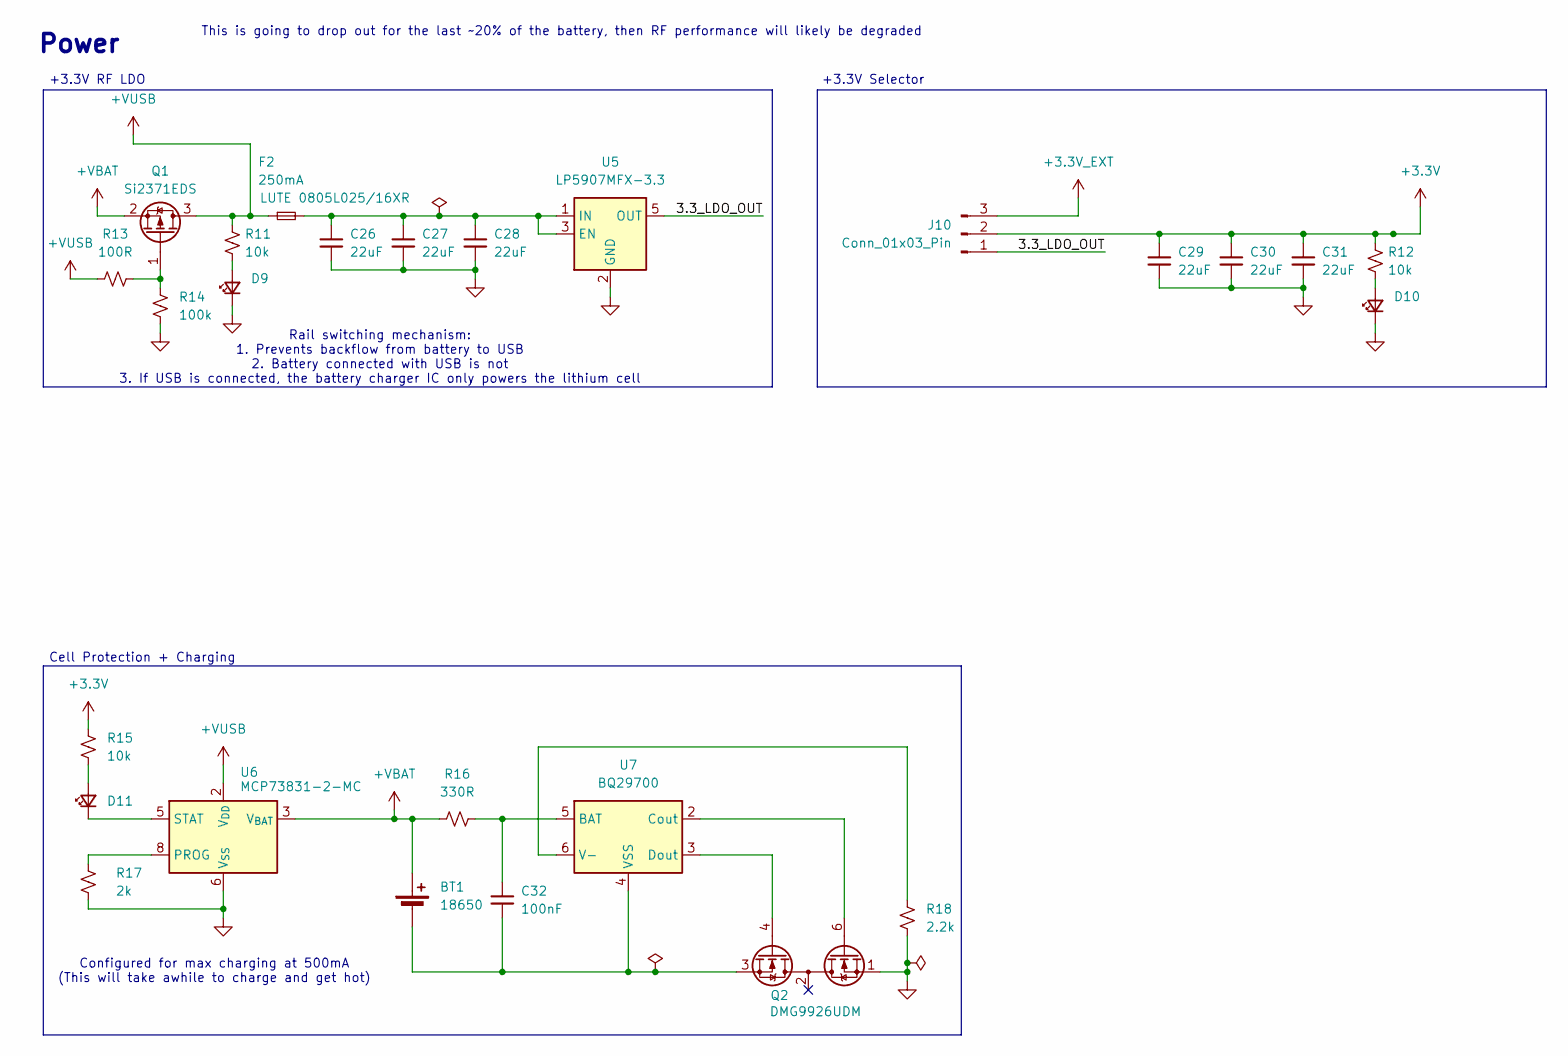
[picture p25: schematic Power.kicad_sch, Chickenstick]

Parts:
BT1: 18650; BatteryHolder_Keystone_1042_1x18650
C26, C27, C28, C29, C30, C31: 22uF; C_0805
C32: 100nF; C_0603
D9, D10, D11: LED_Small; LED_0603
F2: 250mA; Fuse_0805_2012Metric
J10: Conn_01x03_Pin; PinHeader_1x03_P2.54mm_Vertical
Q1: Si2371EDS; SOT-23
Q2: DMG9926UDM; SOT-23-6
R11, R12, R15: 10k; R_0603
R13: 100R; R_0603
R14: 100k; R_0603
R16: 330R; R_0603
R17: 2k; R_0603
R18: 2.2k; R_0603
U5: LP5907MFX-3.3; SOT-23-5
U6: MCP73831-2-MC; DFN-8-1EP_3x2mm_P0.5mm_EP1.7x1.4mm
U7: BQ29700; WSON-6_1.5x1.5mm_P0.5mm

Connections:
+3.3V: C29.1, C30.1, C31.1, J10.2, R12.1, R15.2; also elsewhere on the board
+3.3V_EXT: J10.3; also elsewhere on the board
+VUSB: F2.1, Q1.3 (D), R11.1, R13.1, U6.1 (V_{DD}), U6.2 (V_{DD}); also elsewhere on the board
/Power/3.3_LDO_OUT: J10.1, U5.5 (OUT)
unnamed: BT1.2 (-), C32.2, Q2.3 (S2), U7.4 (VSS)
unnamed: D9.2 (A), R11.2
unnamed: D10.2 (A), R12.2
unnamed: D11.2 (A), R15.1
unnamed: D11.1 (K), U6.5 (STAT)
unnamed: Q1.1 (G), R13.2, R14.1
unnamed: Q2.6 (G1), U7.2 (Cout)
unnamed: Q2.4 (G2), U7.3 (Dout)
unnamed: C26.1, C27.1, C28.1, F2.2, U5.1 (IN), U5.3 (EN)
unnamed: R17.1, U6.8 (PROG)
unnamed: C32.1, R16.2, U7.5 (BAT)
unnamed: R18.1, U7.6 (V-)

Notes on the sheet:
Configured for max charging at 500mA (This will take awhile to charge and get hot)
This is going to drop out for the last ~20% of the battery, then RF performance will likely be degraded
Power
Rail switching mechanism: 1. Prevents backflow from battery to USB 2. Battery connected with USB is not 3. If USB is connected, the battery charger IC only powers the lithium cell
+3.3V RF LDO
Cell Protection + Charging
+3.3V Selector

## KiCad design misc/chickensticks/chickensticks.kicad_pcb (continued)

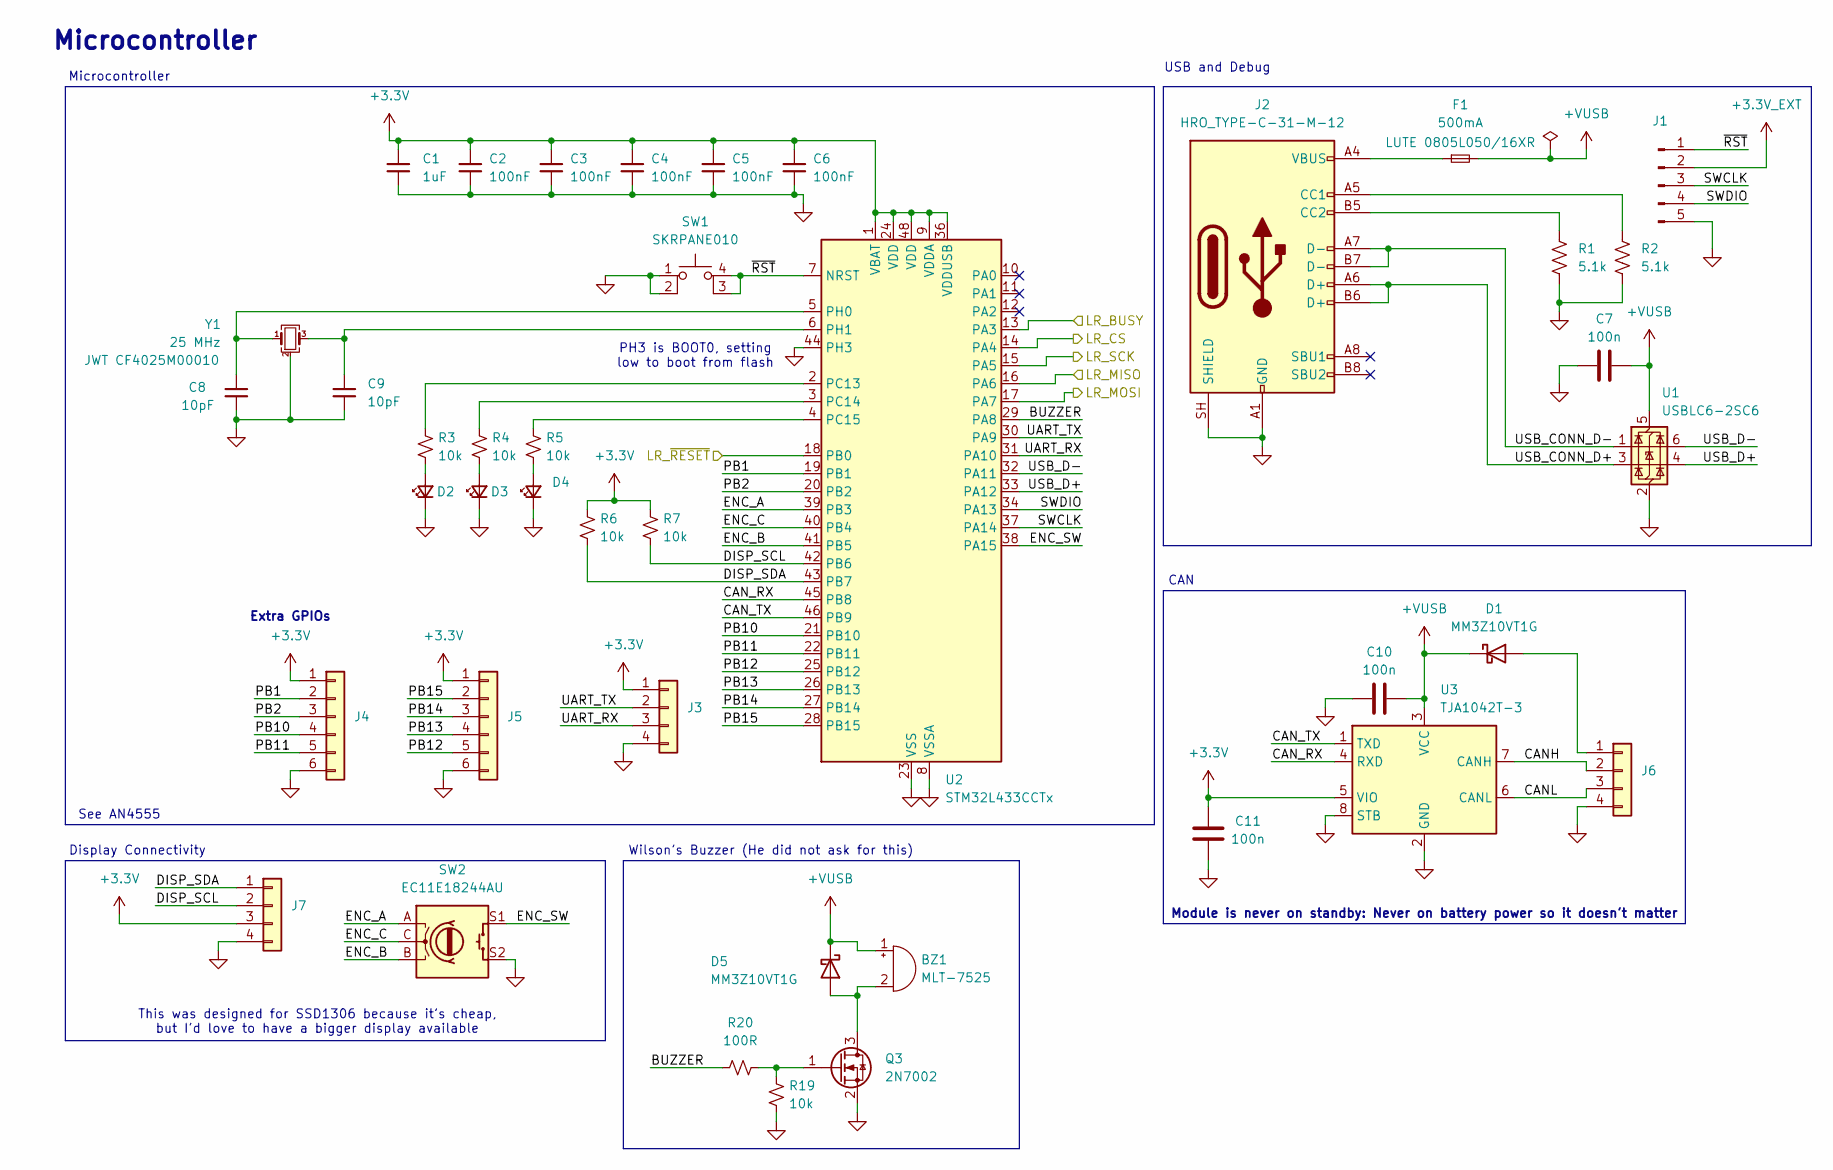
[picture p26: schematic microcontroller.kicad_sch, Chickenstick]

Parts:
BZ1: MLT-7525
C1: 1uF; C_0805
C2, C3, C4, C5, C6: 100nF; C_0603
C7, C10, C11: 100n; C_0603
C8, C9: 10pF; C_0603
D1, D5: MM3Z10VT1G; SOD-323
D2, D3, D4: LED_Small; LED_0603
F1: 500mA; Fuse_0805_2012Metric
J1: Conn_01x05_Pin; PinHeader_1x05_P2.54mm_Vertical
J2: HRO_TYPE-C-31-M-12; USB_C_Receptacle_HRO_TYPE-C-31-M-12
J3, J6, J7: Conn_01x04; PinHeader_1x04_P2.54mm_Vertical
J4, J5: Conn_01x06; PinHeader_1x06_P2.54mm_Vertical
Q3: 2N7002; SOT-23
R1, R2: 5.1k; R_0603
R3, R4, R5, R6, R7, R19: 10k; R_0603
R20: 100R; R_0603
SW1: SKRPANE010
SW2: EC11E18244AU; RotaryEncoder_Alps_EC11E-Switch_Vertical_H20mm_MountingHoles
U1: USBLC6-2SC6; SOT-23-6
U2: STM32L433CCTx; LQFP-48_7x7mm_P0.5mm
U3: TJA1042T-3; SOIC-8_3.9x4.9mm_P1.27mm
Y1: 25 MHz; 3225-4P-L

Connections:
+3.3V: C1.1, C2.1, C3.1, C4.1, C5.1, C6.1, C11.2, J3.1, J4.1, J5.1, J7.3, R6.1, R7.1, U2.1 (VBAT), U2.9 (VDDA), U2.24 (VDD), U2.36 (VDDUSB), U2.48 (VDD), U3.5 (VIO); also elsewhere on the board
+3.3V_EXT: J1.2; also elsewhere on the board
+VUSB: BZ1.1 (+), C7.2, C10.2, D1.1 (K), D5.1 (K), F1.2, U1.5 (VBUS), U3.3 (VCC); also elsewhere on the board
/LoRa Transceiver/LR_BUSY: U2.13 (PA3); also elsewhere on the board
/LoRa Transceiver/LR_CS: U2.14 (PA4); also elsewhere on the board
/LoRa Transceiver/LR_MISO: U2.16 (PA6); also elsewhere on the board
/LoRa Transceiver/LR_MOSI: U2.17 (PA7); also elsewhere on the board
/LoRa Transceiver/LR_SCK: U2.15 (PA5); also elsewhere on the board
/LoRa Transceiver/LR_~RESET: U2.18 (PB0); also elsewhere on the board
/Microcontroller/BUZZER: R20.1, U2.29 (PA8)
/Microcontroller/CANH: J6.2, U3.7 (CANH)
/Microcontroller/CANL: J6.3, U3.6 (CANL)
/Microcontroller/CAN_RX: U2.45 (PB8), U3.4 (RXD)
/Microcontroller/CAN_TX: U2.46 (PB9), U3.1 (TXD)
/Microcontroller/DISP_SCL: J7.2, R7.2, U2.42 (PB6)
/Microcontroller/DISP_SDA: J7.1, R6.2, U2.43 (PB7)
/Microcontroller/ENC_A: SW2.A, U2.39 (PB3)
/Microcontroller/ENC_B: SW2.B, U2.41 (PB5)
/Microcontroller/ENC_C: SW2.C, U2.40 (PB4)
/Microcontroller/ENC_SW: SW2.S1, U2.38 (PA15)
/Microcontroller/PB1: J4.2, U2.19 (PB1)
/Microcontroller/PB2: J4.3, U2.20 (PB2)
/Microcontroller/PB10: J4.4, U2.21 (PB10)
/Microcontroller/PB11: J4.5, U2.22 (PB11)
/Microcontroller/PB12: J5.5, U2.25 (PB12)
/Microcontroller/PB13: J5.4, U2.26 (PB13)
/Microcontroller/PB14: J5.3, U2.27 (PB14)
/Microcontroller/PB15: J5.2, U2.28 (PB15)
/Microcontroller/SWCLK: J1.3, U2.37 (PA14)
/Microcontroller/SWDIO: J1.4, U2.34 (PA13)
/Microcontroller/UART_RX: J3.3, U2.31 (PA10)
/Microcontroller/UART_TX: J3.2, U2.30 (PA9)
/Microcontroller/USB_CONN_D+: J2.A6 (D+), J2.B6 (D+), U1.3 (I/O2)
/Microcontroller/USB_CONN_D-: J2.A7 (D-), J2.B7 (D-), U1.1 (I/O1)
/Microcontroller/USB_D+: U1.4 (I/O2), U2.33 (PA12)
/Microcontroller/USB_D-: U1.6 (I/O1), U2.32 (PA11)
/Microcontroller/~RST: J1.1, SW1.3 (K), SW1.4 (A), U2.7 (NRST)
unnamed: BZ1.2 (-), D5.2 (A), Q3.3 (D)
unnamed: D1.2 (A), J6.1
unnamed: D2.2 (A), R3.2
unnamed: D3.2 (A), R4.2
unnamed: D4.2 (A), R5.2
unnamed: F1.1, J2.A4 (VBUS), J2.A9 (VBUS), J2.B4 (VBUS), J2.B9 (VBUS)
unnamed: J2.A5 (CC1), R2.1
unnamed: J2.B5 (CC2), R1.1
unnamed: Q3.1 (G), R19.1, R20.2
unnamed: R3.1, U2.2 (PC13)
unnamed: R4.1, U2.3 (PC14)
unnamed: R5.1, U2.4 (PC15)
unnamed: C8.1, U2.5 (PH0), Y1.1
unnamed: C9.1, U2.6 (PH1), Y1.3

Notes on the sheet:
Microcontroller
Extra GPIOs
Module is never on standby: Never on battery power so it doesn't matter
See AN4555
Display Connectivity
Wilson's Buzzer (He did not ask for this)
This was designed for SSD1306 because it's cheap, but I'd love to have a bigger display available
CAN
PH3 is BOOT0, setting low to boot from flash
USB and Debug

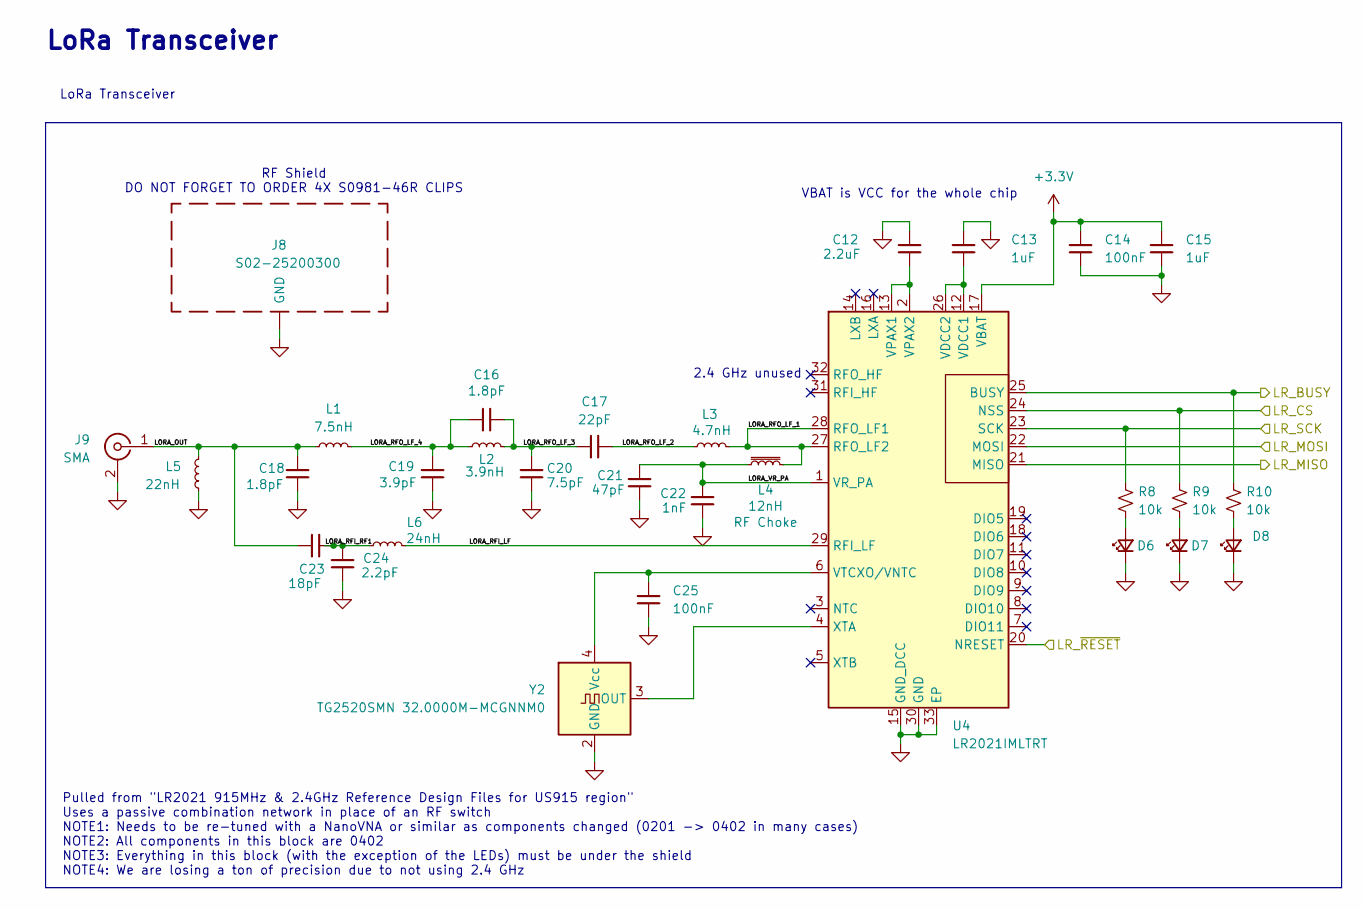
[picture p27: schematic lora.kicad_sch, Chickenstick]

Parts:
C12: 2.2uF; C_0805
C13, C15: 1uF; C_0805
C14, C25: 100nF; C_0603
C16, C18: 1.8pF; C_0402
C17: 22pF; C_0402
C19: 3.9pF; C_0402
C20: 7.5pF; C_0402
C21: 47pF; C_0402
C22: 1nF; C_0402
C23: 18pF; C_0402
C24: 2.2pF; C_0402
D6, D7, D8: LED_Small; LED_0603
J8: S02-25200300; S02-25200300-Outline
J9: SMA; SMA_Amphenol_132203-12_Horizontal
L1: 7.5nH; L_0402
L2: 3.9nH; L_0402
L3: 4.7nH; L_0402
L4: 12nH; L_0402
L5: 22nH; L_0402
L6: 24nH; L_0402
R8, R9, R10: 10k; R_0603
U4: LR2021IMLTRT; QFN-32_EP_5.8x5.8_Pitch0.5mm
Y2: TG2520SMN 32.0000M-MCGNNM0; Oscillator_SMD_SeikoEpson_TG2520SMN-xxx-xxxxxx-4Pin_2.5x2.0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

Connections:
+3.3V: C14.1, C15.1, U4.17 (VBAT); also elsewhere on the board
/LoRa Transceiver/LORA_OUT: C18.2, C23.1, J9.1 (In), L1.1, L5.2
/LoRa Transceiver/LORA_RFI_LF: L6.2, U4.29 (RFI_LF)
/LoRa Transceiver/LORA_RFI_RF1: C23.2, C24.1, L6.1
/LoRa Transceiver/LORA_RFO_LF_1: L3.2, L4.2, U4.27 (RFO_LF2), U4.28 (RFO_LF1)
/LoRa Transceiver/LORA_RFO_LF_2: C17.1, L3.1
/LoRa Transceiver/LORA_RFO_LF_3: C16.1, C17.2, C20.2, L2.2
/LoRa Transceiver/LORA_RFO_LF_4: C16.2, C19.2, L1.2, L2.1
/LoRa Transceiver/LORA_VR_PA: C21.2, C22.2, L4.1, U4.1 (VR_PA)
/LoRa Transceiver/LR_BUSY: R10.1, U4.25 (BUSY); also elsewhere on the board
/LoRa Transceiver/LR_CS: R9.1, U4.24 (NSS); also elsewhere on the board
/LoRa Transceiver/LR_MISO: U4.21 (MISO); also elsewhere on the board
/LoRa Transceiver/LR_MOSI: U4.22 (MOSI); also elsewhere on the board
/LoRa Transceiver/LR_SCK: R8.1, U4.23 (SCK); also elsewhere on the board
/LoRa Transceiver/LR_~RESET: U4.20 (NRESET); also elsewhere on the board
unnamed: D6.2 (A), R8.2
unnamed: D7.2 (A), R9.2
unnamed: D8.2 (A), R10.2
unnamed: C13.2, U4.12 (VDCC1), U4.26 (VDCC2)
unnamed: C12.1, U4.2 (VPAX2), U4.13 (VPAX1)
unnamed: C25.1, U4.6 (VTCXO/VNTC), Y2.4 (Vcc)
unnamed: U4.4 (XTA), Y2.3 (OUT)

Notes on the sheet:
RF Shield DO NOT FORGET TO ORDER 4X S0981-46R CLIPS
2.4 GHz unused
Pulled from "LR2021 915MHz & 2.4GHz Reference Design Files for US915 region" Uses a passive combination network in place of an RF switch NOTE1: Needs to be re-tuned with a NanoVNA or similar as components changed (0201 -> 0402 in many cases) NOTE2: All components in this block are 0402 NOTE3: Every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
VBAT is VCC for the whole chip
LoRa Transceiver

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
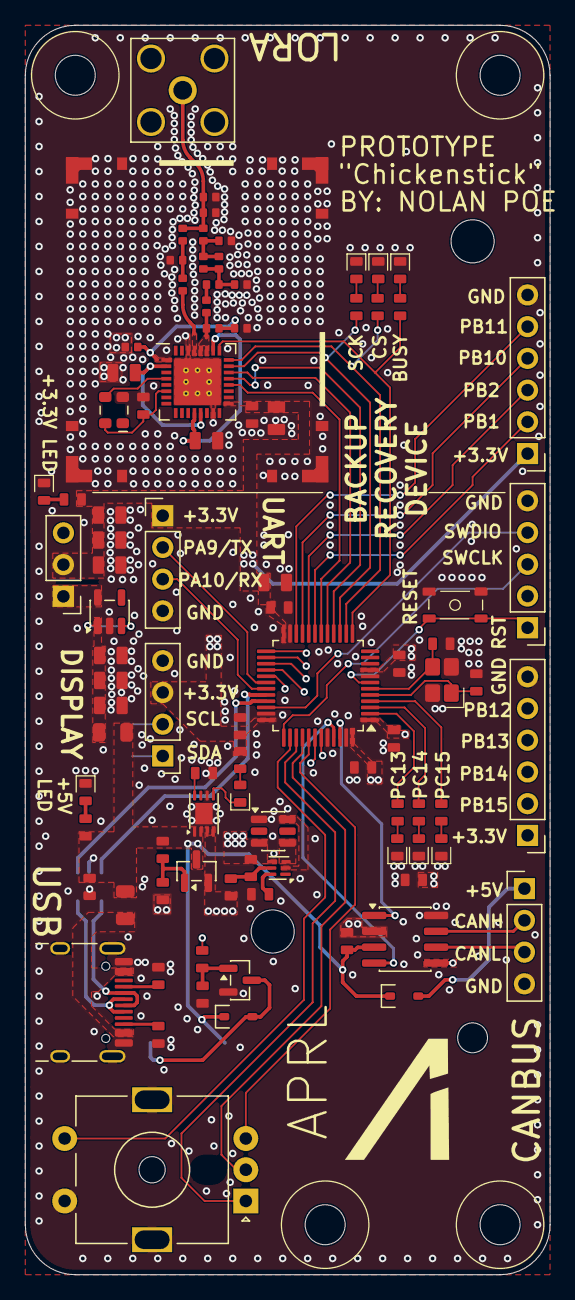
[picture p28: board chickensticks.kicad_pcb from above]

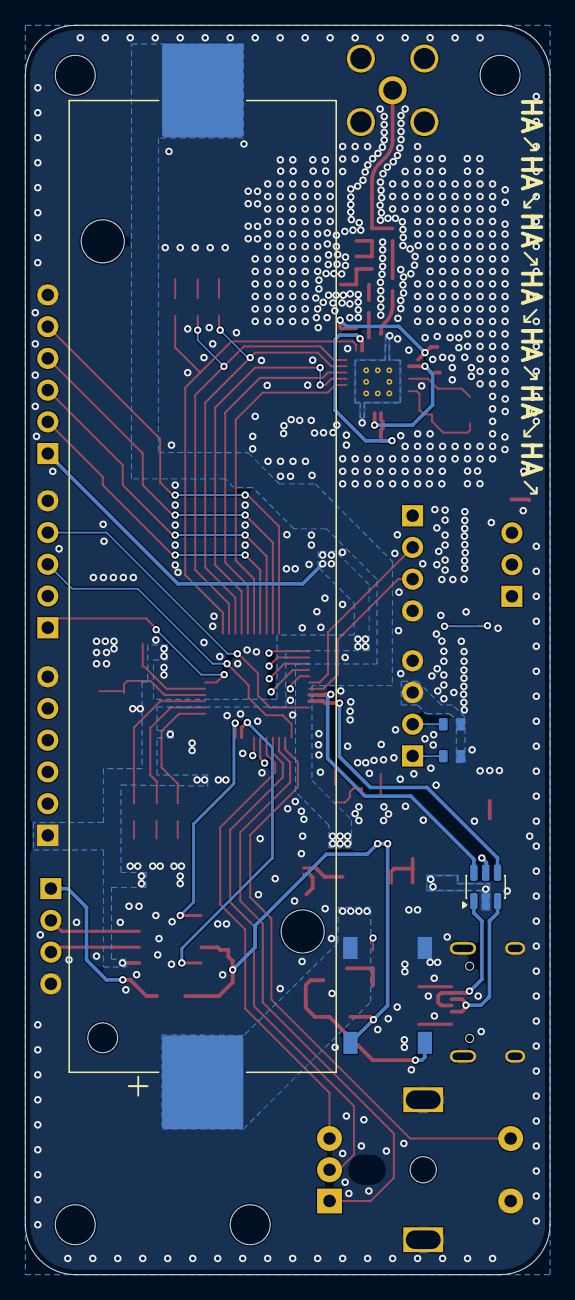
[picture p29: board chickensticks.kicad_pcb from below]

Board: 4 copper layers, 42.0 x 100.0 mm, 101 parts (5 on the bottom side), 81 nets.

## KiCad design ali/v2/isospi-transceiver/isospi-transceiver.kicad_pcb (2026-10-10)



Board: 4 copper layers, 52.0 x 76.0 mm, 76 parts (16 on the bottom side), 50 nets.

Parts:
C1, C18, C23: 1uF; C_0603
C2, C3, C4, C5, C6, C7, C19, C20, C21, C22, C25, C29, C30, C31: 100nF; C_0603
C8, C9, C27, C28: 15pF; C_0603
C10, C11: 2.2uF; C_0603
C12, C13, C14, C15, C16, C17: 22uF; C_0805
C24: 470pF; C_0603
C26: 220nF; C_0603
D1, D2, D3, D4, D5: LED; LED_0603
F1, F2: 500mA; Fuse_0805_2012Metric
H1, H2, H3, H4: MountingHole; MountingHole_3.2mm_M3
J1: Conn_02x01; PinHeader_1x02_P2.54mm_Vertical
J2: Conn_01x05; Molex_CLIK-Mate_503159-0501_1x05-1MP_P1.50mm_Vertical
J3: USB_C_Receptacle_USB2.0_16P; USB_C_Receptacle_G-Switch_GT-USB-7051x
J4: Conn_01x06; QFN-20-1EP_5x5mm_P0.65mm_EP3.35x3.35mm
J6: Screw_Terminal_01x02; PhoenixContact_MSTBV_2,5_2-GF-5,08_1x02_P5.08mm_Vertical_Th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
J7: Conn_01x03; Molex_CLIK-Mate_503159-0301_1x03-1MP_P1.50mm_Vertical
J8: Vertical Ethernet; RJ45_Hanrun_HY951180A_Vertical
R1, R2: 5.1k; R_0603
R3, R4, R5, R6, R7, R14, R16: 10k; R_0603
R8: 120R; R_0603
R9: 1.5k; R_0603
R10, R11, R12, R13: 47R; R_0603
R15: 12.1k; R_0603
R17, R18: 330R; R_0603
SW1: SKRPANE010
U1: STM32H563RIV6; QFN-68-1EP_8x8mm_P0.4mm_EP6.4x6.4mm
U2: AP2112K-3.3; SOT-23-5
U3: TJA1462ATK; HVSON-8-1EP_3x3mm_P0.65mm_EP1.6x2.4mm_ThermalVias
U4: LAN8742AI; VQFN-24-1EP_4x4mm_P0.5mm_EP2.5x2.5mm_ThermalVias
U5: ADBMS6821; LFCSP-32-1EP_5x5mm_P0.5mm_EP2.1x2.1mm_ThermalVias
U6: UCC33420-Q1; VSON-12_4x5mm_P0.65mm
Y1, Y2: 25 MHz; 3225-4P-L

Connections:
+3.3V: C1.1, C2.1, C3.1, C4.1, C5.1, C6.1, C7.1, C15.1, C16.1, C17.1, C18.1, C19.1, C20.1, C21.1, C25.1, C26.1, C29.1, J2.1, J8.3 (TCT), J8.5 (RCT), R4.1, R9.1, R10.1, R11.1, R12.1, R13.1, U1.1 (VBAT), U1.13 (VDDA), U1.19 (VDD), U1.33 (VDD), U1.51 (VDD), U1.68 (VDD), U2.5 (VOUT), U3.5 (VIO), U4.1 (VDD2A), U4.9 (VDDIO), U4.19 (VDD1A), U5.1 (MSTR), U5.6 (VDDS)
+5V: C12.1, C13.1, C14.1, C22.1, C30.1, C31.1, F2.2, J1.2, R3.1, U2.1 (VIN), U2.3 (EN), U3.3 (VCC), U5.12 (VDD), U5.13 (VP)
/Connectivity/CAN+: J7.1, R8.2, U3.7 (CANH)
/Connectivity/CAN-: J7.2, R8.1, U3.6 (CANL)
/Connectivity/ETH_CRS_DV: U1.23 (PA7), U4.11 (CRS_DV/MODE2)
/Connectivity/ETH_MDC: U1.9 (PC1), U4.13 (MDC)
/Connectivity/ETH_MDIO: R9.2, U1.16 (PA2), U4.12 (MDIO)
/Connectivity/ETH_REF_CLK: U1.15 (PA1), U4.14 (~INT/REFCLKO)
/Connectivity/ETH_RXD0: U1.24 (PC4), U4.8 (RXD0/MODE0)
/Connectivity/ETH_RXD1: U1.25 (PC5), U4.7 (RXD1/MODE1)
/Connectivity/ETH_TXD0: U1.34 (PB12), U4.17 (TXD0)
/Connectivity/ETH_TXD1: U1.37 (PB15), U4.18 (TXD1)
/Connectivity/ETH_TX_EN: U1.30 (PB11), U4.16 (TXEN)
/Connectivity/ETH_~RST: U1.14 (PA0), U4.15 (~RST)
/Connectivity/FDCAN_RX: U1.47 (PA11), U3.4 (RXD)
/Connectivity/FDCAN_STDBY: U1.46 (PA10), U3.8 (STB)
/Connectivity/FDCAN_TX: U1.48 (PA12), U3.1 (TXD)
/Connectivity/LED1-REGOFF: J8.9, U4.3 (LED1/REGOFF)
/Connectivity/LED2-INTSEL: J8.12, R16.1, U4.2 (LED2/~INTSEL)
/Connectivity/RX+: J8.6 (RD+), R12.2, U4.23 (RXP)
/Connectivity/RX-: J8.7 (RD-), R13.2, U4.22 (RXN)
/Connectivity/TX+: J8.1 (TD+), R10.2, U4.21 (TXP)
/Connectivity/TX-: J8.2 (TD-), R11.2, U4.20 (TXN)
/Microcontroller/SWCLK: J2.4, U1.52 (PA14(JTCK)
/Microcontroller/SWDIO: J2.2, U1.49 (PA13(JTMS)
/Microcontroller/~RST: J2.5, SW1.3 (K), SW1.4 (A), U1.7 (NRST)
GND: C1.2, C2.2, C3.2, C4.2, C5.2, C6.2, C7.2, C8.2, C9.2, C10.2, C11.2, C12.2, C13.2, C14.2, C15.2, C16.2, C17.2, C18.2, C19.2, C20.2, C21.2, C22.2, C23.2, C24.2, C25.2, C26.2, C27.2, C28.2, C29.2, C30.2, C31.2, D1.1 (K), D2.1 (K), D3.1 (K), D4.1 (K), D5.1 (K), J2.3, J3.A1 (GND), J3.A12 (GND), J3.B1 (GND), J3.B12 (GND), J3.SH (SHIELD), J6.1, J7.3, J8.8, J8.13, J8.14, R1.1, R2.2, R14.1, R15.2, R16.2, R17.2, R18.2, SW1.1, SW1.2, U1.12 (VSSA), U1.18 (VSS), U1.32 (VSS), U1.50 (VSS), U1.62 (BOOT0), U1.67 (VSS), U1.69 (VSS), U2.2 (GND), U3.2 (GND), U3.9 (GND), U4.25 (VSS), U5.9 (GND), U5.33 (GND), Y1.2 (G), Y1.4 (G), Y2.2 (G), Y2.4 (G)
unnamed: C10.1, U1.31 (VCAP)
unnamed: C11.1, U1.66 (VCAP)
unnamed: D1.2 (A), R3.2
unnamed: D2.2 (A), R4.2
unnamed: D3.2 (A), R5.1
unnamed: D4.2 (A), R6.1
unnamed: D5.2 (A), R7.1
unnamed: F1.1, J3.A4 (VBUS), J3.A9 (VBUS), J3.B4 (VBUS), J3.B9 (VBUS)
unnamed: F1.2, J1.1
unnamed: J3.A5 (CC1), R2.1
unnamed: J3.B5 (CC2), R1.2
unnamed: F2.1, J6.2
unnamed: J8.10, R17.1
unnamed: J8.11, R18.1
unnamed: C8.1, U1.5 (PH0), Y1.1
unnamed: C9.1, U1.6 (PH1), Y1.3
unnamed: R15.1, U4.24 (RBIAS)
unnamed: R14.2, U4.10 (RXER/PHYAD0)
unnamed: C23.1, C24.1, U4.6 (VDDCR)
unnamed: C27.1, U4.5 (XTAL1/CLKIN), Y2.1
unnamed: C28.1, U4.4 (XTAL2), Y2.3
unnamed: U6.3 (GNDP), U6.4 (GNDP), U6.5 (GNDP), U6.6 (GNDP)
unnamed: U6.9 (GNDS), U6.10 (GNDS), U6.11 (GNDS), U6.12 (GNDS)

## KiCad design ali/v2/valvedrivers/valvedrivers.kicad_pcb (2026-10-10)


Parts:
H1, H2, H3, H4: MountingHole; MountingHole_3.2mm_M3

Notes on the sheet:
VALVE DRIVERS
Mounting Holes


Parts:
C1: 1uF; C_0603; MPN GRM188D72A105KE01
C2, C3, C4, C5, C6, C7: 100nF; C_0603; MPN GRM188R72A104KA35
C8, C9: 15pF; C_0603; MPN GRM1885C2E150FW07
C10, C11: 2.2uF; C_0603; MPN GRM188R71A225KE15
C12, C13, C14, C15, C16, C17: 22uF; C_0805; MPN GRM21BZ71A226ME15
D1, D2, D3, D4, D5, D6: LED; LED_0603
F1, F3: 500mA; Fuse_0805_2012Metric; MPN 0805L050WR
F2: 10A hold; FuseHolder_Blade_ATO_Littelfuse_FLR_178.6165; MPN 178.6165.0001
F4: 100mA; Fuse_0805_2012Metric; MPN 1206L010/60WR
J1: Conn_02x01; PinHeader_1x02_P2.54mm_Vertical
J2, J7: Conn_01x05; Molex_CLIK-Mate_503159-0501_1x05-1MP_P1.50mm_Vertical; MPN 503159-0501
J3: USB_C_Receptacle_USB2.0_16P; USB_C_Receptacle_G-Switch_GT-USB-7051x; MPN GT-USB-7051A
J4, J5, J6: Screw_Terminal_01x02; PhoenixContact_MSTBV_2,5_2-GF-5,08_1x02_P5.08mm_Vertical_Th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; MPN MSTBV 2,5/ 2-GF-5,08
R1, R2: 5.1k; R_0603; MPN RC0603FR-075K1L
R3: 100k; R_0603; MPN RC0603FR-07100KL
R4, R5, R6, R7, R8, R9, R10, R11: 10k; R_0603; MPN RC0603FR-0710KL
R12: 1k; R_0603; MPN RC0603FR-071KL
SW1: SKRPANE010; MPN SKRPANE010
U1: STM32H563RIV6; QFN-68-1EP_8x8mm_P0.4mm_EP6.4x6.4mm; MPN STM32H563RIV6
U2, U4: LTV-816S; 4-SMD; MPN LTV-816S-TA1-C
U3: AP2112K-3.3; SOT-23-5; MPN AP2112K-3.3TRG1
Y1: 25 MHz; 3225-4P-L; MPN X1E0000210139

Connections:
+3.3V: C1.1, C2.1, C3.1, C4.1, C5.1, C6.1, C7.1, C15.1, C16.1, C17.1, J2.1, J7.1, R5.1, R9.1, R11.1, U1.1 (VBAT), U1.13 (VDDA), U1.19 (VDD), U1.33 (VDD), U1.51 (VDD), U1.68 (VDD), U3.5 (VOUT); also elsewhere on the board
+5V: C12.1, C13.1, C14.1, F3.2, J1.2, J7.5, R4.1, U3.1 (VIN), U3.3 (EN); also elsewhere on the board
+24V: F2.1, J5.2, R3.1; also elsewhere on the board
/Connectivity/ETH_CRS_DV: U1.23 (PA7); also elsewhere on the board
/Connectivity/ETH_MDC: U1.9 (PC1); also elsewhere on the board
/Connectivity/ETH_MDIO: U1.16 (PA2); also elsewhere on the board
/Connectivity/ETH_REF_CLK: U1.15 (PA1); also elsewhere on the board
/Connectivity/ETH_RXD0: U1.24 (PC4); also elsewhere on the board
/Connectivity/ETH_RXD1: U1.25 (PC5); also elsewhere on the board
/Connectivity/ETH_TXD0: U1.34 (PB12); also elsewhere on the board
/Connectivity/ETH_TXD1: U1.37 (PB15); also elsewhere on the board
/Connectivity/ETH_TX_EN: U1.30 (PB11); also elsewhere on the board
/Connectivity/ETH_~RST: U1.14 (PA0); also elsewhere on the board
/Connectivity/FDCAN_RX: U1.47 (PA11); also elsewhere on the board
/Connectivity/FDCAN_STDBY: U1.46 (PA10); also elsewhere on the board
/Connectivity/FDCAN_TX: U1.48 (PA12); also elsewhere on the board
/Driver Set 1/MCU_IN1: U1.55 (PC11); also elsewhere on the board
/Driver Set 1/MCU_IN2: U1.56 (PC12); also elsewhere on the board
/Driver Set 1/MCU_IN3: U1.57 (PB3(JTDO); also elsewhere on the board
/Driver Set 1/MCU_IN4: U1.58 (PB4(NJTRST)); also elsewhere on the board
/Driver Set 1/MCU_IN5: U1.59 (PB5); also elsewhere on the board
/Driver Set 1/MCU_IN6: U1.60 (PB6); also elsewhere on the board
/Driver Set 1/MCU_IN7: U1.61 (PB7); also elsewhere on the board
/Driver Set 1/MCU_IN8: U1.63 (PB8); also elsewhere on the board
/Driver Set 1/MCU_STAT1: U1.64 (PB9); also elsewhere on the board
/Driver Set 1/MCU_STAT2: U1.2 (PC13); also elsewhere on the board
/Driver Set 1/MCU_STAT3: U1.3 (PC14); also elsewhere on the board
/Driver Set 1/MCU_STAT4: U1.4 (PC15); also elsewhere on the board
/Driver Set 1/MCU_STAT5: U1.8 (PC0); also elsewhere on the board
/Driver Set 1/MCU_STAT6: U1.10 (PC2); also elsewhere on the board
/Driver Set 1/MCU_STAT7: U1.11 (PC3); also elsewhere on the board
/Driver Set 1/MCU_STAT8: U1.17 (PA3); also elsewhere on the board
/Driver Set 1/~BUSS_EN: R9.2, U1.45 (PA9), U2.4; also elsewhere on the board
/Driver Set 2/MCU_IN9: U1.20 (PA4); also elsewhere on the board
/Driver Set 2/MCU_IN10: U1.21 (PA5); also elsewhere on the board
/Driver Set 2/MCU_IN11: U1.22 (PA6); also elsewhere on the board
/Driver Set 2/MCU_IN12: U1.26 (PB0); also elsewhere on the board
/Driver Set 2/MCU_STAT9: U1.27 (PB1); also elsewhere on the board
/Driver Set 2/MCU_STAT10: U1.28 (PB2); also elsewhere on the board
/Driver Set 2/MCU_STAT11: U1.29 (PB10); also elsewhere on the board
/Driver Set 2/MCU_STAT12: U1.35 (PB13); also elsewhere on the board
/Microcontroller/IGNIG: J7.2, U1.43 (PC9)
/Microcontroller/SWCLK: J2.4, U1.52 (PA14(JTCK)
/Microcontroller/SWDIO: J2.2, U1.49 (PA13(JTMS)
/Microcontroller/~BRK_STAT: R11.2, U1.44 (PA8), U4.4
/Microcontroller/~RST: J2.5, SW1.3 (K), SW1.4 (A), U1.7 (NRST)
GND: C1.2, C2.2, C3.2, C4.2, C5.2, C6.2, C7.2, C8.2, C9.2, C10.2, C11.2, C12.2, C13.2, C14.2, C15.2, C16.2, C17.2, D1.1 (K), D2.1 (K), D3.1 (K), D4.1 (K), D5.1 (K), D6.1 (K), J2.3, J3.A1 (GND), J3.A12 (GND), J3.B1 (GND), J3.B12 (GND), J3.SH (SHIELD), J4.1, J6.1, J7.4, R1.1, R2.2, SW1.1, SW1.2, U1.12 (VSSA), U1.18 (VSS), U1.32 (VSS), U1.50 (VSS), U1.62 (BOOT0), U1.67 (VSS), U1.69 (VSS), U2.2, U2.3, U3.2 (GND), U4.2, U4.3, Y1.2 (G), Y1.4 (G); also elsewhere on the board
unnamed: C10.1, U1.31 (VCAP)
unnamed: C11.1, U1.66 (VCAP)
unnamed: D1.2 (A), R3.2
unnamed: D2.2 (A), R4.2
unnamed: D3.2 (A), R5.2
unnamed: D4.2 (A), R6.1
unnamed: D5.2 (A), R7.1
unnamed: D6.2 (A), R8.1
unnamed: F1.1, J3.A4 (VBUS), J3.A9 (VBUS), J3.B4 (VBUS), J3.B9 (VBUS)
unnamed: F4.2, R12.1
unnamed: F1.2, J1.1
unnamed: J3.A5 (CC1), R2.1
unnamed: J3.B5 (CC2), R1.2
unnamed: F2.2, J4.2
unnamed: J5.1, R10.1
unnamed: F3.1, J6.2
unnamed: F4.1, J7.3
unnamed: R10.2, U2.1
unnamed: R12.2, U4.1
unnamed: R6.2, U1.40 (PC6)
unnamed: R7.2, U1.41 (PC7)
unnamed: R8.2, U1.42 (PC8)
unnamed: C8.1, U1.5 (PH0), Y1.1
unnamed: C9.1, U1.6 (PH1), Y1.3

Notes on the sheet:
Enables internal voltage regulator for +VCORE See AN5711 section 2.2
MICROCONTROLLER
There will be backfeed from the 3.3V -> 5V line when external 3.3V is applied
USB POWER
POWER
ISOLATED I/O
Pinout in STM32CubeMX
POWER INPUT
12*0.9 = 10.8A (13.2A peak) possible but set to 10 since it is a more common fuse size (standard 10A automotive)
LEDs

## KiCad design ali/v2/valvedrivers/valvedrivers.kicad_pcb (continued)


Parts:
C29, C36: 47uF; KEMET MU VIB; MPN A767KS476M1JLAE036
C30, C31, C37: 100nF; C_0603; MPN GRM188R72A104KA35
C32, C33, C34, C35, C38, C39, C40, C41: 10nF; C_0603; MPN GRM1885C1H103JA01
J10, J11, J12, J13, J14, J15, J16, J17: Conn_01x02; Molex_CLIK-Mate_503159-0201_1x02-1MP_P1.50mm_Vertical; MPN 503159-0201
R24, R25, R26, R27, R28, R29, R30, R31, R32, R33, R34, R35, R36, R37, R38, R39: 10k; R_0603; MPN RC0603FR-0710KL
U7: SN74CBTLV3245A; TSSOP-20_4.4x6.5mm_P0.65mm; MPN SN74CBTLV3245APWR
U8, U9: IPS4140HQ; QFN-48_EP_9.01x7.01_Pitch0.5mm; MPN IPS4140HQ

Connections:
+3.3V: C31.1, R24.1, R25.1, R26.1, R27.1, R32.1, R33.1, R34.1, R35.1, U7.20 (VCC); also elsewhere on the board
+24V: C29.1, C30.1, C36.1, C37.1, U8.49 (VCC), U9.49 (VCC); also elsewhere on the board
/Driver Set 1/MCU_IN1: U7.9 (A8); also elsewhere on the board
/Driver Set 1/MCU_IN2: U7.8 (A7); also elsewhere on the board
/Driver Set 1/MCU_IN3: U7.7 (A6); also elsewhere on the board
/Driver Set 1/MCU_IN4: U7.6 (A5); also elsewhere on the board
/Driver Set 1/MCU_IN5: U7.5 (A4); also elsewhere on the board
/Driver Set 1/MCU_IN6: U7.4 (A3); also elsewhere on the board
/Driver Set 1/MCU_IN7: U7.3 (A2); also elsewhere on the board
/Driver Set 1/MCU_IN8: U7.2 (A1); also elsewhere on the board
/Driver Set 1/MCU_STAT1: R24.2, U8.20 (STAT4); also elsewhere on the board
/Driver Set 1/MCU_STAT2: R25.2, U8.18 (STAT3); also elsewhere on the board
/Driver Set 1/MCU_STAT3: R26.2, U8.16 (STAT2); also elsewhere on the board
/Driver Set 1/MCU_STAT4: R27.2, U8.14 (STAT1); also elsewhere on the board
/Driver Set 1/MCU_STAT5: R32.2, U9.20 (STAT4); also elsewhere on the board
/Driver Set 1/MCU_STAT6: R33.2, U9.18 (STAT3); also elsewhere on the board
/Driver Set 1/MCU_STAT7: R34.2, U9.16 (STAT2); also elsewhere on the board
/Driver Set 1/MCU_STAT8: R35.2, U9.14 (STAT1); also elsewhere on the board
/Driver Set 1/~BUSS_EN: U7.19 (~OE); also elsewhere on the board
GND: C29.2, C30.2, C31.2, C32.2, C33.2, C34.2, C35.2, C36.2, C37.2, C38.2, C39.2, C40.2, C41.2, J10.2, J11.2, J12.2, J13.2, J14.2, J15.2, J16.2, J17.2, R28.2, R29.2, R30.2, R31.2, R36.2, R37.2, R38.2, R39.2, U7.10 (GND), U8.17 (GND), U9.17 (GND); also elsewhere on the board
unnamed: C32.1, J10.1, U8.36 (OUT4), U8.37 (OUT4), U8.38 (OUT4)
unnamed: C33.1, J11.1, U8.39 (OUT3), U8.40 (OUT3), U8.41 (OUT3)
unnamed: C34.1, J12.1, U8.42 (OUT2), U8.43 (OUT2), U8.44 (OUT2)
unnamed: C35.1, J13.1, U8.45 (OUT1), U8.46 (OUT1), U8.47 (OUT1)
unnamed: C38.1, J14.1, U9.36 (OUT4), U9.37 (OUT4), U9.38 (OUT4)
unnamed: C39.1, J15.1, U9.39 (OUT3), U9.40 (OUT3), U9.41 (OUT3)
unnamed: C40.1, J16.1, U9.42 (OUT2), U9.43 (OUT2), U9.44 (OUT2)
unnamed: C41.1, J17.1, U9.45 (OUT1), U9.46 (OUT1), U9.47 (OUT1)
unnamed: R36.1, U7.18 (B1), U9.13 (IN1)
unnamed: R37.1, U7.17 (B2), U9.15 (IN2)
unnamed: R38.1, U7.16 (B3), U9.19 (IN3)
unnamed: R39.1, U7.15 (B4), U9.21 (IN4)
unnamed: R28.1, U7.14 (B5), U8.13 (IN1)
unnamed: R29.1, U7.13 (B6), U8.15 (IN2)
unnamed: R30.1, U7.12 (B7), U8.19 (IN3)
unnamed: R31.1, U7.11 (B8), U8.21 (IN4)


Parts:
C42: 47uF; KEMET MU VIB; MPN A767KS476M1JLAE036
C43, C44: 100nF; C_0603; MPN GRM188R72A104KA35
C45, C46, C47, C48: 10nF; C_0603; MPN GRM1885C1H103JA01
J18, J19, J20, J21: Conn_01x02; Molex_CLIK-Mate_503159-0201_1x02-1MP_P1.50mm_Vertical; MPN 503159-0201
R40, R41, R42, R43, R44, R45, R46, R47: 10k; R_0603; MPN RC0603FR-0710KL
U10: SN74CBTLV3245A; TSSOP-20_4.4x6.5mm_P0.65mm; MPN SN74CBTLV3245APWR
U11: IPS4140HQ; QFN-48_EP_9.01x7.01_Pitch0.5mm; MPN IPS4140HQ

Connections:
+3.3V: C44.1, R40.1, R41.1, R42.1, R43.1, U10.20 (VCC); also elsewhere on the board
+24V: C42.1, C43.1, U11.49 (VCC); also elsewhere on the board
/Driver Set 1/~BUSS_EN: U10.19 (~OE); also elsewhere on the board
/Driver Set 2/MCU_IN9: U10.8 (A7); also elsewhere on the board
/Driver Set 2/MCU_IN10: U10.6 (A5); also elsewhere on the board
/Driver Set 2/MCU_IN11: U10.4 (A3); also elsewhere on the board
/Driver Set 2/MCU_IN12: U10.2 (A1); also elsewhere on the board
/Driver Set 2/MCU_STAT9: R40.2, U11.20 (STAT4); also elsewhere on the board
/Driver Set 2/MCU_STAT10: R41.2, U11.18 (STAT3); also elsewhere on the board
/Driver Set 2/MCU_STAT11: R42.2, U11.16 (STAT2); also elsewhere on the board
/Driver Set 2/MCU_STAT12: R43.2, U11.14 (STAT1); also elsewhere on the board
GND: C42.2, C43.2, C44.2, C45.2, C46.2, C47.2, C48.2, J18.2, J19.2, J20.2, J21.2, R44.2, R45.2, R46.2, R47.2, U10.10 (GND), U11.17 (GND); also elsewhere on the board
unnamed: C45.1, J18.1, U11.36 (OUT4), U11.37 (OUT4), U11.38 (OUT4)
unnamed: C46.1, J19.1, U11.39 (OUT3), U11.40 (OUT3), U11.41 (OUT3)
unnamed: C47.1, J20.1, U11.42 (OUT2), U11.43 (OUT2), U11.44 (OUT2)
unnamed: C48.1, J21.1, U11.45 (OUT1), U11.46 (OUT1), U11.47 (OUT1)
unnamed: R44.1, U10.18 (B1), U11.13 (IN1)
unnamed: R45.1, U10.16 (B3), U11.15 (IN2)
unnamed: R46.1, U10.14 (B5), U11.19 (IN3)
unnamed: R47.1, U10.12 (B7), U11.21 (IN4)


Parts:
C18, C22: 1uF; C_0603; MPN GRM188D72A105KE01
C19, C20, C21, C27, C28: 100nF; C_0603; MPN GRM188R72A104KA35
C23: 470pF; C_0603; MPN GRM1885C1H471JA01
C24: 220nF; C_0603; MPN GRM188R71H224KAC4
C25, C26: 15pF; C_0603; MPN GRM1885C2E150FW07
J8: Vertical Ethernet; RJ45_Hanrun_HY951180A_Vertical; MPN HY951180A
J9: Conn_01x03; Molex_CLIK-Mate_503159-0301_1x03-1MP_P1.50mm_Vertical; MPN 503159-0301
R13: 1.5k; R_0603; MPN RC0603FR-071K5L
R14, R15, R16, R17: 47R; R_0603; MPN RC0603FR-0747RL
R18, R20: 10k; R_0603; MPN RC0603FR-0710KL
R19: 12.1k; R_0603; MPN RT0603BRD0712K1L
R21, R22: 330R; R_0603; MPN RC0603FR-07330RL
R23: 120R; R_0603; MPN AC0603FR-07120RL
U5: LAN8742AI; VQFN-24-1EP_4x4mm_P0.5mm_EP2.5x2.5mm_ThermalVias; MPN LAN8742AI-CZ-TR
U6: TJA1462ATK; HVSON-8-1EP_3x3mm_P0.65mm_EP1.6x2.4mm_ThermalVias; MPN TJA1462ATK/0Z
Y2: 25 MHz; 3225-4P-L; MPN X1E0000210139

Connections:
+3.3V: C18.1, C19.1, C20.1, C21.1, C24.1, C28.1, J8.3 (TCT), J8.5 (RCT), R13.1, R14.1, R15.1, R16.1, R17.1, U5.1 (VDD2A), U5.9 (VDDIO), U5.19 (VDD1A), U6.5 (VIO); also elsewhere on the board
+5V: C27.1, U6.3 (VCC); also elsewhere on the board
/Connectivity/ETH_CRS_DV: U5.11 (CRS_DV/MODE2); also elsewhere on the board
/Connectivity/ETH_MDC: U5.13 (MDC); also elsewhere on the board
/Connectivity/ETH_MDIO: R13.2, U5.12 (MDIO); also elsewhere on the board
/Connectivity/ETH_REF_CLK: U5.14 (~INT/REFCLKO); also elsewhere on the board
/Connectivity/ETH_RXD0: U5.8 (RXD0/MODE0); also elsewhere on the board
/Connectivity/ETH_RXD1: U5.7 (RXD1/MODE1); also elsewhere on the board
/Connectivity/ETH_TXD0: U5.17 (TXD0); also elsewhere on the board
/Connectivity/ETH_TXD1: U5.18 (TXD1); also elsewhere on the board
/Connectivity/ETH_TX_EN: U5.16 (TXEN); also elsewhere on the board
/Connectivity/ETH_~RST: U5.15 (~RST); also elsewhere on the board
/Connectivity/FDCAN_RX: U6.4 (RXD); also elsewhere on the board
/Connectivity/FDCAN_STDBY: U6.8 (STB); also elsewhere on the board
/Connectivity/FDCAN_TX: U6.1 (TXD); also elsewhere on the board
GND: C18.2, C19.2, C20.2, C21.2, C22.2, C23.2, C24.2, C25.2, C26.2, C27.2, C28.2, J8.8, J8.13, J8.14, J9.3, R18.1, R19.2, R20.2, R21.2, R22.2, U5.25 (VSS), U6.2 (GND), U6.9 (GND), Y2.2 (G), Y2.4 (G); also elsewhere on the board
unnamed: J8.10, R21.1
unnamed: J8.11, R22.1
unnamed: J8.6 (RD+), R16.2, U5.23 (RXP)
unnamed: J8.7 (RD-), R17.2, U5.22 (RXN)
unnamed: J8.1 (TD+), R14.2, U5.21 (TXP)
unnamed: J8.2 (TD-), R15.2, U5.20 (TXN)
unnamed: J9.1, R23.2, U6.7 (CANH)
unnamed: J9.2, R23.1, U6.6 (CANL)
unnamed: J8.9, U5.3 (LED1/REGOFF)
unnamed: J8.12, R20.1, U5.2 (LED2/~INTSEL)
unnamed: R19.1, U5.24 (RBIAS)
unnamed: R18.2, U5.10 (RXER/PHYAD0)
unnamed: C22.1, C23.1, U5.6 (VDDCR)
unnamed: C25.1, U5.5 (XTAL1/CLKIN), Y2.1
unnamed: C26.1, U5.4 (XTAL2), Y2.3

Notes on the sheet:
ETH
CAN



Board: 4 copper layers, 85.0 x 76.0 mm, 144 parts (51 on the bottom side), 110 nets.

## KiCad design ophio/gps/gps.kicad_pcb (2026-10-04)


Board: 4 copper layers, 43.0 x 34.0 mm, 28 parts (0 on the bottom side), 18 nets.

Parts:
C1, C2, C3, C5, C7, C9: 22uF; C_0805
C4, C6, C8, C12, C14: 100nF; C_0603
C10, C11: 33pF; C_0603
C13: 100pF; C_0603
D1: LED_Small; LED_0603
F1: 100mA hold; Fuse_0805_2012Metric
H1, H2, H3, H4: MountingHole; MountingHole_3.2mm_M3
J1: Conn_01x07; PinHeader_1x07_P2.54mm_Vertical
J2: SMA; SMA_BAT_Wireless_BWSMA-KWE-Z001
L1: 68 nH; LQW18AN68NG8Z
R1, R2: 10k; R_0603
U1: AP2112K-3.3; SOT-23-5
U2: TXS0108EPW; TSSOP-20_4.4x6.5mm_P0.65mm
U3: LC29H; ublox_NEO

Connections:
+2.8V: C6.1, C12.1, U2.19 (VCCB), U3.7 (VDD_EXT)
+3.3V: C4.1, C5.1, C7.1, C8.1, C9.1, C10.1, C11.1, R2.1, U1.5 (VOUT), U2.2 (VCCA), U3.22 (V_BCKP), U3.23 (VCC)
+5V: C1.1, C2.1, C3.1, F1.1, R1.1, U1.1 (VIN), U1.3 (EN), U2.10 (OE)
/I2C_SCL: U2.16 (B4), U3.19 (I2C_SCL)
/I2C_SDA: U2.15 (B5), U3.18 (I2C_SDA)
/RXD: U2.18 (B2), U3.21 (RXD)
/TXD: U2.17 (B3), U3.20 (TXD)
/~RESET: U2.20 (B1), U3.8 (~RESET)
GND: C1.2, C2.2, C3.2, C4.2, C5.2, C6.2, C7.2, C8.2, C9.2, C10.2, C11.2, C12.2, C13.2, C14.2, D1.1 (K), J1.7, J2.2 (Ext), R1.2, U1.2 (GND), U2.11 (GND), U3.10 (GND), U3.12 (GND), U3.13 (GND), U3.24 (GND)
unnamed: D1.2 (A), R2.2
unnamed: F1.2, J1.1
unnamed: J1.2, U2.6 (A5)
unnamed: J1.3, U2.5 (A4)
unnamed: J1.4, U2.4 (A3)
unnamed: J1.5, U2.3 (A2)
unnamed: J1.6, U2.1 (A1)
unnamed: J2.1 (In), L1.2, U3.11 (RF_IN)
unnamed: C13.1, C14.1, L1.1, U3.9 (VDD_RF)

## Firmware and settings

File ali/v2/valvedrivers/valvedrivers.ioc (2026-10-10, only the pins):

Mcu.UserName=STM32H563RIVx
PA0.GPIO_Label=ETH_nRST
PA0.Signal=GPIO_Output
PA1.Signal=ETH_REF_CLK
PA10.GPIO_Label=FDCAN_STDBY
PA10.Signal=GPIO_Output
PA11.Signal=FDCAN1_RX
PA12.Signal=FDCAN1_TX
PA13(JTMS/SWDIO).Signal=DEBUG_JTMS-SWDIO
PA14(JTCK/SWCLK).Signal=DEBUG_JTCK-SWCLK
PA2.Signal=ETH_MDIO
PA3.GPIO_Label=DRV2_4_STAT
PA3.Signal=GPIO_Input
PA4.GPIO_Label=DRV3_1_IN
PA4.Signal=GPIO_Output
PA5.GPIO_Label=DRV3_2_IN
PA5.Signal=GPIO_Output
PA6.GPIO_Label=DRV3_3_IN
PA6.Signal=GPIO_Output
PA7.Signal=ETH_CRS_DV
PA8.GPIO_Label=nBRK_STAT
PA8.Signal=GPIO_Input
PA9.GPIO_Label=nBUSS_EN
PA9.Signal=GPIO_Input
PB0.GPIO_Label=DRV3_4_IN
PB0.Signal=GPIO_Output
PB1.GPIO_Label=DRV3_1_STAT
PB1.Signal=GPIO_Input
PB10.GPIO_Label=DRV3_3_STAT
PB10.Signal=GPIO_Input
PB11.Signal=ETH_TX_EN
PB12.Signal=ETH_TXD0
PB13.GPIO_Label=DRV3_4_STAT
PB13.Signal=GPIO_Input
PB15.Signal=ETH_TXD1
PB2.GPIO_Label=DRV3_2_STAT
PB2.Signal=GPIO_Input
PB3(JTDO/TRACESWO).GPIO_Label=DRV1_3_IN
PB3(JTDO/TRACESWO).Signal=GPIO_Output
PB4(NJTRST).GPIO_Label=DRV1_4_IN
PB4(NJTRST).Signal=GPIO_Output
PB5.GPIO_Label=DRV2_1_IN
PB5.Signal=GPIO_Output
PB6.GPIO_Label=DRV2_2_IN
PB6.Signal=GPIO_Output
PB7.GPIO_Label=DRV2_3_IN
PB7.Signal=GPIO_Output
PB8.GPIO_Label=DRV2_4_IN
PB8.Signal=GPIO_Output
PB9.GPIO_Label=DRV1_1_STAT
PB9.Signal=GPIO_Input
PC0.GPIO_Label=DRV2_1_STAT
PC0.Signal=GPIO_Input
PC1.Signal=ETH_MDC
PC11.GPIO_Label=DRV1_1_IN
PC11.Signal=GPIO_Output
PC12.GPIO_Label=DRV1_2_IN
PC12.Signal=GPIO_Output
PC13.GPIO_Label=DRV1_2_STAT
PC13.Signal=GPIO_Input
PC14-OSC32_IN(OSC32_IN).GPIO_Label=DRV1_3_STAT
PC14-OSC32_IN(OSC32_IN).Signal=GPIO_Input
PC15-OSC32_OUT(OSC32_OUT).GPIO_Label=DRV1_4_STAT
PC15-OSC32_OUT(OSC32_OUT).Signal=GPIO_Input
PC2.GPIO_Label=DRV2_2_STAT
PC2.Signal=GPIO_Input
PC3.GPIO_Label=DRV2_3_STAT
PC3.Signal=GPIO_Input
PC4.Signal=ETH_RXD0
PC5.Signal=ETH_RXD1
PC6.GPIO_Label=USER_LED_1
PC6.Signal=GPIO_Output
PC7.GPIO_Label=USER_LED_2
PC7.Signal=GPIO_Output
PC8.GPIO_Label=USER_LED_3
PC8.Signal=GPIO_Output
PC9.GPIO_Label=IGNIG
PC9.Signal=GPIO_Output
PH0-OSC_IN(PH0).Signal=RCC_OSC_IN
PH1-OSC_OUT(PH1).Signal=RCC_OSC_OUT

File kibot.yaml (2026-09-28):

# Shared KiBot configuration for all APRL boards.
#
# Usage (from repo root):
#   cd <board-dir> && kibot -c ../kibot.yaml -e <board>.kicad_sch -b <board>.kicad_pcb
#
# Or via just:
#   just kibot ali/v2/valvedrivers
#   just kibot-all
#
# Every board uses this config. All symbols, footprints and 3D models come from
# kicadlibs/ in this repo, so the 3D outputs below render the same on any
# machine and in CI.

kibot:
  version: 1

globals:
  filters:
    - filter: Ignore PcbDraw missing components
      number: 103
    - filter: Ignore missing KiCad config, not in docker images
      number: 8
    # kicadlibs/models/ carries everything except four packages KiCad ships no STEP for
    # (QFN-68, VQFN-32, TG2520SMN, ublox_NEO). Those still warn.
    - filter: Ignore missing KiCad 3D models, not in docker images
      number: 10
    - filter: Ignore missing KiCad config from KiAuto, not in docker images
      number: 58
      regex: kicad_common.json
    - filter: Logo and other graphics-only footprints keep the REF** reference
      number: 147
      regex: 'REF\*\*'
    - filter: render_3d is intentional; blender_export needs Blender in the image
      number: 143
      regex: blender_export
  restore_project: true
  time_reformat: false

preflight:
  check_zone_fills: true
  erc: true
  drc:
    enabled: true
    filters:
      - filter: "Connectors that intentionally extend outside the board outline"
        error: "silk_over_copper"
        regex: "clipped by solder mask"
  set_text_variables:
    - name: "git_hash"
      command: 'git log -1 --format="%h" $KIBOT_PCB_NAME'
      before: "Git:"
    - name: "date"
      command: "date --iso-8601=minutes"

filters:
  - name: only_parts_with_mpn
    comment: 'Only parts with a manufacturer part number (logos, holes and blank-MPN parts are left out)'
    type: generic
    include_only:
      - column: 'MPN'
        regex: '\S'

outputs:
  # -------------------------------------------------------------------------
  # Documentation
  # -------------------------------------------------------------------------

  - name: print_sch
    comment: Schematic PDF
    type: pdf_sch_print
    dir: Schematic

  - name: print_board
    comment: PCB layer PDFs (B&W and colour)
    type: pcb_print
    dir: Schematic
    options:
      format: PDF
      scaling: 0
      autoscale_margin_x: 50
      autoscale_margin_y: 50
      pages:
        - sheet: FrontBW
          layers:
            - { layer: User.Drawings, color: "#000000" }
            - { layer: F.Cu,          color: "#F0F0F0" }
            - { layer: F.Paste,       color: "#C4C4C4" }
            - { layer: F.Silkscreen,  color: "#000000" }
            - { layer: Edge.Cuts,     color: "#575757" }
            - { layer: User.Eco1,     color: "#000000" }
            - { layer: User.Comments, color: "#6c6c6c" }
        - sheet: In1BW
          layers:
            - { layer: User.Drawings, color: "#000000" }
            - { layer: In1.Cu,        color: "#000000" }
            - { layer: Edge.Cuts,     color: "#575757" }
            - { layer: User.Comments, color: "#6c6c6c" }
        - sheet: In2BW
          layers:
            - { layer: User.Drawings, color: "#000000" }
            - { layer: In2.Cu,        color: "#000000" }
            - { layer: Edge.Cuts,     color: "#575757" }
            - { layer: User.Comments, color: "#6c6c6c" }
        - sheet: BottomBW
          layers:
            - { layer: User.Drawings, color: "#000000" }
            - { layer: B.Cu,          color: "#F0F0F0" }
            - { layer: B.Paste,       color: "#C4C4C4" }
            - { layer: B.Silkscreen,  color: "#000000" }
            - { layer: Edge.Cuts,     color: "#575757" }
            - { layer: User.Comments, color: "#6c6c6c" }
        - sheet: FrontColor
          layers:
            - { layer: User.Drawings, color: "#000000" }
            - { layer: User.Eco1,     color: "#000080" }
            - { layer: F.Cu,          color: "#B3FFB3" }
            - { layer: F.Paste,       color: "#FF8A8A" }
            - { layer: F.Silkscreen,  color: "#626262" }
            - { layer: Edge.Cuts,     color: "#FF8000" }
            - { layer: User.Comments, color: "#6c6c6c" }
        - sheet: In1Color
          layers:
            - { layer: User.Drawings, color: "#000000" }
            - { layer: In1.Cu,        color: "#B3FFB3" }
            - { layer: Edge.Cuts,     color: "#FF8000" }
            - { layer: User.Eco1,     color: "#000080" }
            - { layer: User.Comments, color: "#6c6c6c" }
        - sheet: In2Color
          layers:
            - { layer: User.Drawings, color: "#000000" }
            - { layer: In2.Cu,        color: "#B3FFB3" }
            - { layer: Edge.Cuts,     color: "#FF8000" }
            - { layer: User.Eco1,     color: "#000080" }
            - { layer: User.Comments, color: "#6c6c6c" }
        - sheet: BottomColor
          layers:
            - { layer: User.Drawings, color: "#000000" }
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

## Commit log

2026-09-21 mfw tcs
    [PCC-SMP-V-K.step, Texas_HTSSOP-14-1EP_4.4x5mm_P0.65mm_EP3.4x5mm_Mask3.155x3.255mm.step, UCC33420-Q1_VSON-12.step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]
2026-09-24 mfw pts
    [178.6165.0001.step, CAP-SMD_BD10.0-L10.3-W10.3-LS11.0-FD.step, Fuse_1812L_Littelfuse.step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]
2026-09-26 mfw LCs
    [CP_Elec_8x12.2_KEMET_A767_KS.step, ThermoBoard.kicad_pcb, ThermoBoard.kicad_sch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]
2026-09-26 chore: regenerate -noct footprint variants
2026-09-27 Update load cells to use timer pins
    [Texas_RHB0032E_VQFN-32-1EP_5x5mm_P0.5mm_EP3.45x3.45mm.step, load-cell.kicad_pcb, load-cell.kicad_sch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]
2026-09-27 Adjust VD boundaries
    [drivers.kicad_sch, valvedrivers.kicad_pcb]
2026-09-27 Small stuff
    [analog.kicad_sch, cjc.kicad_sch, pressuretransducers.kicad_pcb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]
2026-09-27 Minor updates
    [Oscillator_SCTF_SX3M_3.2x2.5mm.step, analog.kicad_sch, connectivity.kicad_sch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]
2026-09-27 Update revision numbers
    [microcontroller.kicad_sch]
2026-09-27 Swap to sync'd ADS1261s on LC, update README and clean up Just scripts, some frame changes too.
    [TSSOP-24_4.4x7.8mm_P0.65mm.step, ali-template.kicad_pcb, ali-template.kicad_sch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]
2026-09-27 Fix ERC issues
    [drivers.kicad_sch, pressuretransducers.kicad_pcb, valvedrivers.kicad_pcb]
2026-09-27 Idk why this package change keeps happening
    [microcontroller.kicad_sch, valvedrivers.kicad_pcb]
2026-09-27 Remove LCSC fields and point STM32H5 package to APRL's instead of KiCad's
    [connectivity.kicad_sch, microcontroller.kicad_sch, pressuretransducers.kicad_pcb]
2026-09-28 Minor thermocouple updates
    [analog.kicad_sch, connectivity.kicad_sch, load-cell.kicad_pcb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]
2026-09-28 Globally remove LCSC labels, update MPNs and IOCs, add +5V monitoring to DAQs, fix some footprints
    [SMDIP-4_W9.53mm.step, ThermoBoard.kicad_pcb, analog.kicad_sch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]
2026-09-28 Small documentation
    [analog.kicad_sch, cjc.kicad_sch, thermocouples.kicad_pcb]
2026-09-28 Re-link loadcell reference designators
    [load-cell.kicad_pcb]
2026-09-28 Small TC changes, small just script fixes
    [thermocouples.kicad_pcb]
2026-09-28 Fix models for kicad 10.0.5
    [ali-template.kicad_pcb, load-cell.kicad_pcb, microcontroller.kicad_sch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]
2026-09-28 the great flatpak and kicad 10.0.6 migration
    [Power.kicad_sch, analog.kicad_sch, cjc.kicad_sch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]
2026-09-28 The other half of the great 10.0.6 migration
    [analog.kicad_sch, load-cell.kicad_pcb, microcontroller.kicad_sch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]
2026-09-28 Fix IPS4140 paste pattern
    [valvedrivers.kicad_pcb]
2026-09-29 Add ignition port to valve driver board, set up CANBUS keepouts
    Daniel please don't see this I am embarassed
    [connectivity.kicad_sch, drivers.kicad_sch, microcontroller.kicad_sch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]
2026-09-29 Add more commentary
    [analog.kicad_sch, cjc.kicad_sch, microcontroller.kicad_sch]
2026-10-01 Small thermocouple notes: Considering changing biasing scheme
    [analog.kicad_sch, thermocouples.kicad_pcb, valvedrivers.kicad_pcb]
2026-10-03 Make valve driver zones look slightly nicer
    Just for a screenshot, they're not perfect angles still
    [valvedrivers.kicad_pcb]
2026-10-04 Fix 50R/60R widths
    [connectivity.kicad_sch, load-cell.kicad_pcb, microcontroller.kicad_sch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]
2026-10-04 Document setup, update template, and use an ampersand when referring to APRL
    [Power.kicad_sch, ThermoBoard.kicad_pcb, ThermoBoard.kicad_sch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]
2026-10-04 Add note on ADC selection
    [analog.kicad_sch, connectivity.kicad_sch]
2026-10-04 Remove RC filter from thermocouple schematic
    [thermocouples.kicad_pcb]
2026-10-04 Fix TC clearance issue
    [thermocouples.kicad_pcb]
2026-10-10 Begin prep for second board review
    [Fuse_1206_3216Metric.step, ali-template.kicad_pcb, ali-template.kicad_sch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]
2026-10-10 fix erc
    [analog.kicad_sch, microcontroller.kicad_sch, thermocouples.kicad_sch]

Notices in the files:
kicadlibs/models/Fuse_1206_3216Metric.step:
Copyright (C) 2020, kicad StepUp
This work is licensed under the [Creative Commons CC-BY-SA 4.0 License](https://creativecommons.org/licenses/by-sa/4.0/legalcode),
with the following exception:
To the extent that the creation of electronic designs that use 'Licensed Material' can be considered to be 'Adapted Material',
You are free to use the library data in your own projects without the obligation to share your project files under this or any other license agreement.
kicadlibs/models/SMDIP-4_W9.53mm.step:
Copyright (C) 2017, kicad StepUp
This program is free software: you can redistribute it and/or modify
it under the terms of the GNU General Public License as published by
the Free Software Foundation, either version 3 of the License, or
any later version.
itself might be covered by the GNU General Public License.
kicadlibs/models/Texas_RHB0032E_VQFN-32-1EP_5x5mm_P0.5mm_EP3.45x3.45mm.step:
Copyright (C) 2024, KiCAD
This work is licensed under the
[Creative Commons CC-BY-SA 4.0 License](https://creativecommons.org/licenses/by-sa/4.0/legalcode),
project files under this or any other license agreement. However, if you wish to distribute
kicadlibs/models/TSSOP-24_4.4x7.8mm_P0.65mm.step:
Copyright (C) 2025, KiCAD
